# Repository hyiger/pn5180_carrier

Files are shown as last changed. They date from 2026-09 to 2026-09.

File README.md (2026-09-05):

# PN5180 8-Bay NFC Reader Carrier

Carrier board that lets 4 or 8 PN5180 breakout modules plug in over ~30 cm cables with
Molex CLIK-Mate 1.50 mm dual-row (2×5) positive-lock connectors (CLIK-Mate is the white
latching family used on the Prusa LoveBoard) and share one SPI bus with a Seeed Studio
XIAO ESP32C6 soldered flat at the top centre of the board. It runs from the printer's 24 V supply through an MP1584EN buck
module soldered flat onto the carrier. Every part is SMD except the buck module's four
through-hole pads; the XIAO is soldered flat by its castellations. A 74HC138 decodes
3 address lines into the 8 chip selects; a 74HC151 muxes the 8 BUSY lines back to a
single GPIO. The PN5180's IRQ pin is not used — BUSY is the only handshake the SPI
protocol needs.

**GPIO cost: 9 of the XIAO's 11 pins** — SCK, MOSI, MISO, A0, A1, A2, /EN, BUSY, /RST.
D6 and D7 are spare.

Author: hyiger · Rev 1.4 · KiCad 10 files (saved with 10.0.6; KiCad 9 and older cannot open them)

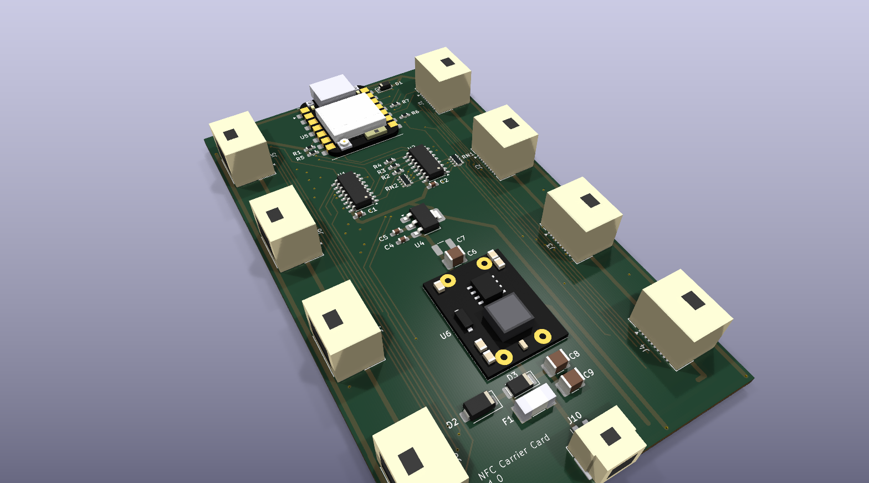
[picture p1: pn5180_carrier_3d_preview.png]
3D preview of the carrier


## Files

| File | Purpose |
|---|---|
| `pn5180_carrier.kicad_pro` | Project file — open this in KiCad 10 |
| `pn5180_carrier.kicad_sch` | Schematic (single A3 sheet, all symbols embedded) |
| `pn5180_carrier.kicad_pcb` | 2-layer PCB, 62.5 × 106.5 mm. Layout in progress: J1–J8 now carry the 2×5 503148-1090 footprints (swapped 2026-09-05) but their tracks still need re-routing; a few other nets unrouted; mounting holes not yet placed. All 35 footprints reference a 3D model |
| `carrier.kicad_sym` + `sym-lib-table` | Project-local symbol library (same symbols, for editing) |
| `carrier.pretty/` + `fp-lib-table` | Project-local footprints: the XIAO castellated SMD pattern (plus the older 2×7-socket version, geometry from Seeed's OPL library), the MP1584EN module pads, the CLIK-Mate 503148-1090 2×5 receptacle (from Molex's catalog drawing — KiCad ships no dual-row CLIK-Mate footprint), and copies of the stock 502494-0270 (J10) and NANO2 (F1) footprints that differ only in pointing at a project 3D model |
| `pn5180_carrier_schematic.pdf` / `.png` | Rendered schematic, no KiCad needed |
| `pn5180_carrier_bom.csv` | Full BOM: refs, qty, MPN, Mouser #, footprint, DNP flag |
| `pn5180_carrier_mouser_order.csv` | One-board order list for Mouser's BOM tool (populated parts and cable-side parts with spare terminals) |
| `gerbers/`, `gerbers.zip` | Preview gerber/drill export of the unfinished layout, still with the 1×10 connectors — not a fab package |
| `check_netlist.py` | Asserts the exported netlist against the intended connectivity (`kicad-cli sch export netlist --format kicadsexpr -o net.txt pn5180_carrier.kicad_sch`, then `python3 check_netlist.py net.txt`) |
| `gen_kicad.py` | Historical generator that produced the schematic, symbol library, footprints and BOM through rev 1.3 (KiCad 7 format). The KiCad files have been hand-edited since and are authoritative — don't re-run it over them |
| `CLAUDE.md`, `MEMORY.md` | Design guide and decision log: verified part data, layout state, ERC/DRC baseline, open items |
| `.gitignore` | Keeps KiCad's transient files (`.history/`, `.kicad_prl`, lock files), kicad-cli check outputs and `renders/` out of git |
| `carrier.3dshapes/` | Simplified VRML 3D models (boxes with the right envelopes and colours) for the parts KiCad ships no model for: the 2×5 and 1×2 CLIK-Mate receptacles, the XIAO (flat, plus a socketed variant), the MP1584EN module (black no-trimmer type), the NANO2 fuse. Generated by `tools/gen_3d_models.py`; drop in vendor STEP files when you have them |
| `tools/` | `gen_clikmate_2x5_fp.py` (the 503148-1090 footprint), `gen_xiao_smd_fp.py` (the XIAO castellated footprint), `gen_3d_models.py` (the models above), `render_3d_preview.py` (top, isometric and close-up PNGs of the board via `kicad-cli pcb render`; run with KiCad's bundled Python) |
| `pn5180_carrier_3d_preview.png` | Rendered 3D view of the board with those models |

Footprints reference the stock KiCad libraries and every name was verified against
the 10.0 library set (`Capacitor_SMD`, `Diode_SMD`, `Package_SO`, `Resistor_SMD`, …). If a newer
library renames one, reassign it in the footprint tool — nothing in the netlist
depends on the footprint. Command-line checks use KiCad's `kicad-cli`: `sch erc`,
`pcb drc --schematic-parity`, and `sch export netlist` followed by `check_netlist.py`.

## Connector pinouts

### J1–J8: bay connectors (Molex 503148-1090, CLIK-Mate 1.50 mm 2×5 dual-row right-angle SMT)

Build cables by Molex circuit number: cavity *n* of the 503149-1000 housing is signal *n*,
and signals 1–9 follow the first nine positions of the common red PN5180 module's header,
so the module end is a straight 1-to-9 run plus the second GND (cavity 10 into the same
module GND as cavity 9). Molex's catalog drawings number the two rows as stacked pairs —
odd circuits (1, 3, 5, 7, 9) in one row, even (2, 4, 6, 8, 10) in the other — which puts
5V over 3V3, /RST over NSS, MOSI over MISO, SCK over BUSY and the two GNDs in the last
column. That pairing and the receptacle's lead order are read off the drawings rather than
dimensioned, so before crimping the first cable confirm on Molex's 503149/503148 sales
drawings which end is circuit 1 (and from which face the drawing looks), which row carries
the odd circuits, and the 502579 terminal's insertion orientation. On the PCB the
receptacle's ten leads come out in one 0.75 mm-pitch line, numbered 1 to 10 from the pin-1
end (chamfer and triangle on the footprint), offset half a pitch toward pin 10 because the
even-row tails jog sideways. Pin 10 is a second GND: run it as a separate wire twisted with
SCK and crimp both returns into the module's GND at the far end, which tightens the SCK
return loop over the 30 cm. Verify the module's header order before building cables.

| Pin | Signal | Notes |
|---|---|---|
| 1 | 5V | From carrier 5V rail (module TVDD / RF power) |
| 2 | 3V3 | From the carrier LDO (U4), direct |
| 3 | /RST | Shared by all bays |
| 4 | NSS | Bay-specific, from 74HC138 output *n* |
| 5 | MOSI | Shared |
| 6 | MISO | Shared (module tri-states when NSS high) |
| 7 | SCK | Shared |
| 8 | BUSY | Bay-specific, to 74HC151 input *n*, 100k pull-down (RN1/RN2) |
| 9 | GND | |
| 10 | GND | Second return — twist with SCK in the harness |

Bay *n* ↔ J(n+1) ↔ 74HC138 Y*n* ↔ 74HC151 D*n*. Bay 0 is address 000, bay 7 is 111.

Most PN5180 modules expect both 5 V and 3.3 V supplied (3.3 V for VBAT/PVDD, 5 V for the
RF stage), so the carrier feeds both. If your modules regulate 3.3 V onboard and drive
that pin as an *output*, leave pin 2 out of the cable rather than paralleling two LDOs.

### U5: Seeed XIAO ESP32C6, soldered flat on castellated pads

Pin numbers follow Seeed's own symbol/footprint: 1–11 = D0–D10, 12 = 3V3 out, 13 = GND,
14 = 5V (USB VBUS). Pins 1 (D0) and 14 (5V) are at the USB end. The footprint
(`carrier:Seeed_XIAO_ESP32C6_SMD`) puts 14 SMD pads of 1.5 × 2.5 mm under the module's
castellations (2.54 mm pitch, rows 17.8 mm apart, extending 1.25 mm past the module edge
for the fillet) and carries the 21 × 17.8 mm outline, the USB-C overhang and an antenna
marker — place the XIAO with the USB end at the carrier's top edge and the antenna end
inboard, and keep copper off both layers under the antenna end. The socketed alternative
(`Seeed_XIAO_2x7_Socket`, two Würth 61300711821 1×7 headers) stays in the library.

| Signal | XIAO pin | Symbol pin | GPIO* | Note |
|---|---|---|---|---|
| SCK | D8 | 9 | 19 | hardware SPI SCK, via R6 33 Ω |
| MISO | D9 | 10 | 20 | hardware SPI MISO |
| MOSI | D10 | 11 | 18 | hardware SPI MOSI, via R7 33 Ω |
| /EN | D3 | 4 | 21 | → 74HC138 /E1 (acts as NSS) |
| A0 | D0 | 1 | 0 | |
| A1 | D1 | 2 | 1 | |
| A2 | D2 | 3 | 2 | |
| BUSY | D4 | 5 | 22 | 74HC151 output (I²C SDA pin, unused as such) |
| /RST | D5 | 6 | 23 | shared reset to all bays |
| spare | D6 | 7 | 16 | NC (UART0 TX) |
| spare | D7 | 8 | 17 | NC (UART0 RX) |
| 3V3 out | — | 12 | | NC — the carrier has its own 3V3 LDO |
| GND | — | 13 | | |
| 5V | — | 14 | | from carrier 5V through D1 |

\* GPIO numbers per Seeed's pin diagram; write firmware with the `D0…D10` names from the
board's `pins_arduino.h` and they can't be wrong. `SPI.begin()` with no arguments uses
D8/D9/D10.

**Power path:** Seeed states the XIAO's 5V pin is the raw USB VBUS and that an external
supply must go through a diode. D1 (PMEG2010AEH, 0.3 V drop at our current) does that, so
USB can stay plugged in for flashing while the carrier is powered — neither source can
push into the other. The XIAO's own LDO makes its 3.3 V from ~4.7 V; that's fine. With the
carrier unpowered, USB alone runs the XIAO and D1 keeps VBUS out of the carrier's 5 V rail.

### J10: 24 V input (Molex 502494-0270, CLIK-Mate 2.00 mm 1×2 right-angle SMT)

| Pin | Signal |
|---|---|
| 1 | +24 V from the printer PSU |
| 2 | GND (printer PSU return) |

**Tapping the Core One.** Take it from the PSU's 24 V output terminals — put a crimped
fork/spade terminal under the existing screw next to the xBuddy's lead, positive and
return together, 22 AWG is plenty. Check polarity with a meter before you plug the
carrier in; the connector is keyed but the PSU end isn't. Load is ≤ ~0.4 A at 24 V worst
case (the module's 1.5 A limit at 5 V), typically well under that, so the PSU's headroom
is not a concern. The xBuddy's MMU port also carries firmware-switched 24 V, but it's only
enabled when an MMU is configured, so the PSU terminals are the practical tap.

**Input stage (all on the carrier):** F1 1 A (NANO2 451/453, fast-acting — see open item 13) → D2 SMAJ28A TVS (clamps motor
regen spikes; a reversed input forward-biases it and blows F1) → D3 PMEG6030EP reverse
Schottky (keeps the reversed input off C8/C9 and the module; F1 still blows through D2,
so replace it after fixing the miswire) → C8/C9 2 × 10 µF 50 V → U6.

**Buck (U6): MP1584EN mini module, mounted flat.** The footprint has four 3 mm
through-hole pads on the module's 18.54 × 8.13 mm pad rectangle; lay the module on the
carrier and solder down through its own plated holes, or stand it on four header-pin
stubs — both work on the same pads. IN pads at the "IN" silk end, OUT at "OUT", "+" marks
the top row. Module pad labels vary between makers, so check the module's own silkscreen
against the footprint before soldering.

Three things about this module on a 24 V rail:

- It's rated 28 V max. The TVS (28 V standoff, clamping from ~31 V) and C8/C9 are what
  keep spikes off it — don't leave them out to save parts.
- It's the **fixed 5 V output** variant (black PCB, no trimmer — the one modelled in
  3D). Don't substitute the adjustable type: a bumped pot can put up to 20 V into the
  readers and the XIAO. Check 5.0 V at OUT+ on the bench before fitting the readers.
- The seller's own guidance is 1.5 A continuous without a heatsink. The carrier's real
  draw is well under 1 A (one RF field at a time), so that's fine; give it some copper
  under the pads anyway.

### Cables (~30 cm)

Bay cable: 503149-1000 dual-row housing at the carrier with 10 × 502579 terminals on
24–28 AWG stranded wire — the terminal takes insulation of 0.78–1.28 mm OD, so use
thin-wall UL1061/UL1571-type wire and check the specific wire's maximum OD against 1.28 mm
(common UL1007 24 AWG at ~1.5 mm is too fat, and some UL1061 24 AWG is specified at
1.3 mm); 24 AWG for 5V/GND is plenty at ≤ 0.25 A per bay — and a 2.54 mm DuPont-style
female on the module end (or solder to the module header). Power: the 24 V cable stays on the 2.00 mm family, 502439-0200 housing
with 502438 terminals on 22 AWG. The XIAO is soldered to the carrier, so bay and power
cables are the only cables.

The housing latches inside the receptacle (the CLIK; one inner lock on the 10-circuit
housing) and releases with a squeeze — no tools. Molex's hand crimpers are expensive
(distributor listings name 200218-7400 for the 1.50 mm 502579 and 63819-2800 for the
2.00 mm 502438 — not checked against Molex's tooling spec); both are small open-barrel
terminals and a small-barrel ratchet crimper (Engineer PA-09 or an IWISS SN-01BM-class
tool) does the job — pull-test the first few crimps, because with 24–28 AWG in a 1.5 mm
terminal the tool is what makes or breaks a cable. Molex also sells pre-crimped CLIK-Mate 1.50 leads
(79758-1011: 300 mm, 24 AWG UL1061, terminal on both ends, packs of 10 at RS) — cut one
end off and solder it to the module header if you'd rather skip crimping.

Eight 30 cm unterminated stubs hanging off one SPI bus is a real transmission-line load,
so the design takes three precautions:

- **R6/R7 (33 Ω) in series with SCK and MOSI**, a few mm from the XIAO's SCK/MOSI pads and
  before the bus fans out — proper source termination for the star, taking the edge off
  the ESP32's ~2 ns rise times. Fit 0 Ω if you scope it and it's clean; 47–68 Ω if you
  see ringing.
- **SPI clock ≤ 1 MHz.** The PN5180 doesn't need more for inventory polling, and a 1 µs
  bit period gives the reflections on a 30 cm stub (a few ns round trip) time to settle.
- **Lowest ESP32 drive strength that works:** `gpio_set_drive_capability((gpio_num_t)D8,
  GPIO_DRIVE_CAP_0)` (and `D10` for MOSI) slows the edges further.

Route GND wires as close to SCK as the harness allows. MISO is driven by the PN5180 (slower
edges) and needs nothing extra. NSS/BUSY see one stub each and are fine.

## How the selection logic works

- `A0..A2` → 74HC138 address inputs **and** both 74HC151 select inputs.
- `/EN` → 74HC138 `/E1` (G2A). Low = the addressed bay's NSS goes low; high = every NSS high.
  Wire the library's "NSS" pin to `/EN` and it just works — the library toggles NSS,
  the decoder routes it.
- `BUSY` (XIAO D4, symbol pin 5) is the 74HC151 output = the BUSY of the addressed bay. Wire
  it to the library's "BUSY" pin.
- `/E2` is grounded, `E3` tied high; 74HC151 `/E` grounded (always enabled).
- R6/R7 sit between the ESP32 and the SCK/MOSI bus (nets `SCK_IN`/`MOSI_IN` on the ESP32 side).
- Pull-ups on `/EN` and `/RST` and pull-downs on `A0..A2` define everything while the
  ESP32 is booting or unplugged. The 4×100k arrays RN1/RN2 keep unfitted bays' BUSY
  inputs from floating. Bay *n* uses element (*n* mod 4)+1 of RN(1 + *n*÷4): pin
  (*n* mod 4)+1 to the signal and its opposite pin (8, 7, 6, 5) to GND — the standard
  1–8/2–7/3–6/4–5 pairing.

**Rule:** change `A0..A2` only while `/EN` is high, or two NSS lines can glitch low
during the decoder transition.

## Firmware sketch (ATrappmann PN5180 library)

```cpp
// Seeed XIAO ESP32C6 soldered to the carrier (Arduino-ESP32 core 3.x, board "XIAO_ESP32C6")
#define PIN_A0   D0
#define PIN_A1   D1
#define PIN_A2   D2
#define PIN_EN   D3     // -> 74HC138 /E1, acts as "NSS" for the addressed bay
#define PIN_BUSY D4     // <- 74HC151 Y
#define PIN_RST  D5
#define BAYS      8     // 4 for a half-populated board
// SCK D8 / MISO D9 / MOSI D10 are the board's hardware SPI pins

PN5180ISO15693 nfc(PIN_EN, PIN_BUSY, PIN_RST);   // one instance for all bays

void selectBay(uint8_t n) {
  digitalWrite(PIN_EN, HIGH);            // deselect everything before changing address
  digitalWrite(PIN_A0, n & 1);
  digitalWrite(PIN_A1, (n >> 1) & 1);
  digitalWrite(PIN_A2, (n >> 2) & 1);
}

void setup() {
  pinMode(PIN_A0, OUTPUT); pinMode(PIN_A1, OUTPUT); pinMode(PIN_A2, OUTPUT);
  pinMode(PIN_EN, OUTPUT); digitalWrite(PIN_EN, HIGH);
  nfc.begin();                           // SPI on D8/D9/D10; keep the SPI clock <= 1 MHz
  gpio_set_drive_capability((gpio_num_t)D8,  GPIO_DRIVE_CAP_0);   // soften SCK/MOSI edges
  gpio_set_drive_capability((gpio_num_t)D10, GPIO_DRIVE_CAP_0);
  // shared /RST: pulse once, then finish the post-reset handshake per bay
  digitalWrite(PIN_RST, LOW);  delay(10);
  digitalWrite(PIN_RST, HIGH); delay(10);
  for (uint8_t b = 0; b < BAYS; b++) {
    selectBay(b);
    while (!(nfc.getIRQStatus() & IDLE_IRQ_STAT)) {}   // add a timeout in real code
    nfc.clearIRQStatus(0xFFFFFFFF);
  }
}

void loop() {
  for (uint8_t b = 0; b < BAYS; b++) {
    selectBay(b);
    nfc.setupRF();                       // RF on, this bay only
    uint8_t uid[8];
    bool present = (nfc.getInventory(uid) == ISO15693_EC_OK);
    nfc.setRF_off();                     // field off before moving to the next bay
    updateBay(b, present, uid);          // debounce: 2-3 misses before "removed"
  }
}
```

The stock library's `while (digitalRead(BUSY))` loops have no timeout; add one
(a few ms) so an empty bay or a wedged module can't hang the sweep.

## Layout notes

The 2-layer PCB in `pn5180_carrier.kicad_pcb` follows these rules; the current routing
state and the ERC/DRC baseline are tracked in `MEMORY.md`.

- Ground plane on one layer; SPI signals short, routed as a star or short daisy chain
  from U5 to the bay connectors. With 8 loads plus cable capacitance, ≤ 1 MHz SPI.
- U5 at the top centre, USB-C end at the top board edge (the rule is a 1–2 mm overhang;
  as placed the module edge sits 0.5 mm inside and only the USB-C shell is 1.05 mm proud),
  antenna end (opposite the USB) pointing inboard with
  a copper keep-out on both layers under it. The XIAO is soldered flat by its
  castellations (no sockets); it also has an external-antenna u.FL if the rack's metal
  gets in the way.
- Bay connectors down both long edges (J5–J8 left, J1–J4 right), in bay order, so cables
  don't cross. The 503148 receptacles are SMT: ten 0.55 mm signal pads at 0.75 mm pitch
  in one line at the rear (reflow, or drag-solder with plenty of flux) and two solder-nail
  pads ("MP" in the footprint) at the front corners — the nails, not the signal pins, take
  the cable-pull load, so give them full paste and don't thin the copper under them.
  Right-angle parts: the cable leaves flat along the board plane. The 2×5 body is 11.8 mm
  long against the old 1×10's 24.0 mm, so the connector columns can tighten up. **J1–J8
  were swapped to the 2×5 footprint on 2026-09-05** (same positions and orientations,
  nail pads outboard); their tracks still have to be re-routed, then refill zones, run
  DRC and regenerate the gerbers (CLAUDE.md open item 12).
- R6/R7 within a few mm of U5 pins 9/11 (D8 SCK / D10 MOSI), before the traces fan out.
- U1/U2 near U5 (short A0–A2, /EN, BUSY traces); the eight NSS/BUSY lines then run out
  to the connector edge.
- U6 module: C8/C9 right at its IN pads, a solid GND pour under it, and keep it away from
  the SPI lines and the XIAO's antenna (it switches at ~1.5 MHz with a small inductor).
- F1/D2/D3 near J10; C6/C7 and C4 near U4; C1/C2 within a few mm of their IC VCC pins.
- U4 (SOT-223) with a copper pour on the tab (tab = OUTPUT, part of the 3V3 net); at ~200 mA on 3V3 it dissipates ~0.35 W.
- M3 mounting holes are still to be added (not in the schematic).
- For a 4-bay build simply leave J5–J8 (and RN2) unpopulated. Firmware `BAYS = 4`.

## BOM (all SMD except U6's four pads)

Rev 1.4. Every symbol in the schematic carries `Manufacturer`, `MPN` and `Mouser` fields,
so KiCad's own BOM export reproduces this table. `pn5180_carrier_mouser_order.csv` can be
uploaded directly to Mouser's BOM tool.

| Ref | Qty | Part | Mouser # | Footprint |
|---|---|---|---|---|
| U1 | 1 | TI SN74HC138DR | 595-SN74HC138DR | Package_SO:SOIC-16_3.9x9.9mm_P1.27mm |
| U2 | 1 | TI SN74HC151DR | 595-SN74HC151DR | Package_SO:SOIC-16_3.9x9.9mm_P1.27mm |
| U4 | 1 | TI TLV1117LV33DCYR, 3.3 V 1 A ceramic-stable LDO | 595-TLV1117LV33DCYR | Package_TO_SOT_SMD:SOT-223-3_TabPin2 |
| J1–J8 | 8 | Molex 503148-1090, CLIK-Mate 1.50 mm dual-row RA SMT receptacle 2×5 (1 A/contact) | 538-503148-1090 | carrier:Molex_CLIK-Mate_503148-1090_2x05-1MP_P1.50mm_Horizontal |
| U5 | 1 | Seeed Studio XIAO ESP32C6 (SKU 113991182) — user-supplied, soldered flat | 713-113991182 (verify) | carrier:Seeed_XIAO_ESP32C6_SMD |
| D1 | 1 | Nexperia PMEG2010AEH, Schottky 20 V 1 A, SOD-123 | 771-PMEG2010AEH | Diode_SMD:D_SOD-123 |
| J10 | 1 | Molex 502494-0270, CLIK-Mate 2.00 mm RA SMT receptacle 1×2 (24 V in) | 538-502494-0270 | carrier:Molex_CLIK-Mate_502494-0270_1x02-1MP_P2.00mm_Horizontal (local copy of the stock footprint, with 3D model) |
| U6 | 1 | MP1584EN mini buck module, 22 × 17 mm, fixed 5 V output (no trimmer) — user-supplied (Amazon) | — | carrier:MP1584EN_Module_22x17 |
| F1 | 1 | Littelfuse 0453001.MR, 1 A, NANO2 (451/453 is the fast-acting series — see open item 13) | 576-0453001.MR | carrier:Fuse_Littelfuse-NANO2-451_453 (local copy of the stock footprint, with 3D model) |
| D2 | 1 | Littelfuse SMAJ28A TVS, 28 V standoff, SMA | 576-SMAJ28A | Diode_SMD:D_SMA |
| D3 | 1 | Nexperia PMEG6030EP Schottky 60 V 3 A (reverse polarity) | 771-PMEG6030EP | Diode_SMD:D_SOD-128 |
| C8, C9 | 2 | Murata GRM32ER71H106KA12L, 10 µF 50 V X7R 1210 | 81-GRM32ER71H106KA12L | Capacitor_SMD:C_1210_3225Metric_Pad1.33x2.70mm_HandSolder |
| R1–R5 | 5 | Yageo RC0603FR-0710KL, 10k 1% 0603 | 603-RC0603FR-0710KL | Resistor_SMD:R_0603_1608Metric_Pad0.98x0.95mm_HandSolder |
| R6, R7 | 2 | Yageo RC0603FR-0733RL, 33 Ω 1% 0603 (SCK/MOSI series) | 603-RC0603FR-0733RL | Resistor_SMD:R_0603_1608Metric_Pad0.98x0.95mm_HandSolder |
| RN1, RN2 | 2 | Yageo YC164-FR-07100KL, 4×100k 1% isolated array | 603-YC164-FR-07100KL | Resistor_SMD:R_Array_Convex_4x0603 |
| C1, C2 | 2 | Murata GRM188R71H104KA93D, 100 nF 50 V X7R 0603 | 81-GRM188R71H104KA93D | Capacitor_SMD:C_0603_1608Metric_Pad1.08x0.95mm_HandSolder |
| C4 | 1 | Murata GRM188R61A106KE69D, 10 µF 10 V X5R 0603 | 81-GRM188R61A106KE69D | Capacitor_SMD:C_0603_1608Metric_Pad1.08x0.95mm_HandSolder |
| C5 | 1 | Murata GRM188R60J226MEA0D, 22 µF 6.3 V X5R 0603 | 81-GRM188R60J226MEA0D | Capacitor_SMD:C_0603_1608Metric_Pad1.08x0.95mm_HandSolder |
| C6 | 1 | Taiyo Yuden MSASJ32MAB5227MPNDT1, 220 µF 6.3 V X5R 1210 | 963-MSASJ32MAB5227MP | Capacitor_SMD:C_1210_3225Metric_Pad1.33x2.70mm_HandSolder |
| C7 | 1 | Same — **DNP**, parallel pads for extra bulk | 963-MSASJ32MAB5227MP | Capacitor_SMD:C_1210_3225Metric_Pad1.33x2.70mm_HandSolder |

Cable side:

| Part | Mouser # | Qty / board | Use |
|---|---|---|---|
| Molex 503149-1000 CLIK-Mate 1.50 dual-row positive-lock plug housing 2×5 | 538-503149-1000 | 8 | Bay cables |
| Molex 502579-0000 CLIK-Mate 1.50 crimp terminal, 24–28 AWG, cut strip of 100 | 538-502579-0000-CT | 100 (80 needed) | Bay cables |
| Molex 502439-0200 CLIK-Mate 2.00 positive-lock housing 1×2 | 538-502439-0200 | 1 | 24 V cable |
| Molex 502438-0100 CLIK-Mate 2.00 crimp terminal, loose, 22–26 AWG | 538-502438-0100 | 2 (+spares) | 24 V cable |

Stock check on Mouser, 2026-09-04/05: 503148-1090 1,696 in stock, minimum 1, $1.98 at 10;
503149-1000 7,865, minimum 1, $0.44 at 10; 502579-0000 cut strip 33,700, minimum 100,
$5.70 per 100. An aggregator snapshot the same day showed the receptacle at DigiKey
(11,852, minimum 1), Newark (63, minimum 1) and Arrow (6,046), and the housing at Newark
(6,475, minimum 10); no obsolescence notice on any of these parts.
The finer 503429-0000 terminal (26–30 AWG) is reel-only (20,000) — don't spec it. The
vertical (top-entry) dual-row receptacle is 503154-1090 (2 A/contact, a two-row land
pattern); the right-angle part used here is rated 1.0 A per contact, 30 mating cycles — a
bay draws ≤ 0.25 A.

Mouser numbers follow Mouser's manufacturer-prefix + MPN scheme (595 = TI, 538 = Molex,
603 = Yageo, 81 = Murata, 710 = Würth, 771 = Nexperia, 713 = Seeed, 576 = Littelfuse). 963-MSASJ32MAB5227MP was read from the product page; the
others follow the scheme. Double-check stock and packaging (cut tape vs. reel) at checkout.

Capacitor notes:

- C6 is a 6.3 V X5R part on the 5 V rail. That's inside its rating, but class-2 ceramics
  lose capacitance under DC bias — expect roughly a quarter of its nominal 220 µF at
  5 V. Together with the MP1584EN module's own output capacitor that's plenty for the
  ~250 mA RF-on step; C7 gives you a second set of pads if the rail shows sag when a
  bay's field switches on.
- U4 is a TLV1117LV33, designed for ceramic output capacitors (TI specifies ≥ 10 µF,
  any ESR, stable at 0 mA load). C5's 22 µF 0603 is worth roughly 10–12 µF after
  DC-bias derating at 3.3 V, which meets that minimum; for more margin use a 22 µF in
  0805 or two 0603s in parallel. Don't substitute a classic AMS1117/TLV1117 here
  without changing C5 to a tantalum — those parts need output ESR to stay stable.
- TLV1117LV limits: Vin ≤ 5.5 V (6 V absolute). Fine on a regulated 5 V rail, but never
  feed J10 from an unregulated "5 V" adapter that idles at 6–7 V. Dropout is ~0.45 V at
  1 A, so 3V3 holds up even if the input droops to 4 V.

## Going to 16 bays

Swap U1 for a 74HC154 (4-to-16), add a second 74HC151 selected by A3 and two more
arrays: 6 select GPIOs, 10 of the XIAO's 11 pins with SPI and /RST. The ESP32-C6 has one
user SPI host, so 16 stubs stay on one bus — keep it at ≤ 1 MHz with the source
termination, or move to an MCU with a second SPI port.

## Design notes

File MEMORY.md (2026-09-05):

# MEMORY — PN5180 8-bay carrier

Context and decision log for whoever picks this up. Written on the evening of 2026-09-03
(local, −07:00; the generator stamps its files 2026-09-04 because that session's clock
ran on UTC) by the design session this log calls "rev 1.5" — the script itself only
stamps rev 1.3, while the sheet title block and README are at 1.4 since 2026-09-05; the
owner has hand-edited since.
Updated 2026-09-04 for the KiCad 10 migration, with measured layout and check status
(history item 11, "Layout state", "Check status"), and 2026-09-05 for the 2×5 CLIK-Mate
switch (item 12), the 3D models (item 13), the flat-mounted XIAO (item 14) and the
fixed-5 V U6 confirmation (item 7). All clock times below are local.

## Owner and purpose

- Owner: **hyiger** (use that name on documents, never a real name or email; git commits
  as `hyiger` with the GitHub no-reply address). Public repo since 2026-09-04:
  https://github.com/hyiger/pn5180_carrier (branch `main`). Experienced FDM
  practitioner and developer; runs a Prusa Core One and a Bambu H2D; maintains Filament DB
  (TypeScript/Electron, NFC spool tags via OpenPrintTag/SLIX2, ACR1552U reader, PN5180
  multi-reader spec) and PrusaSlicer/OrcaSlicer profile tooling. Comfortable with SMD
  hand assembly, KiCad, crimping.
- Purpose: a "spool rack" that detects which NFC-tagged spool is in which of 8 bays.
  One PN5180 breakout per bay, ~30 cm cable to this carrier, ESP32-C6 reports to
  Filament DB over Wi-Fi. Powered from the Core One's 24 V PSU.

## How the design got here (chronological, with reasons)

1. **Architecture**: 8 PN5180 on one SPI bus. RST, SCK, MOSI, MISO shared; NSS and BUSY
   per board. BUSY is mandatory (the PN5180 SPI handshake needs it); IRQ is optional and
   was later dropped entirely. 74HC138 (3 addr + enable → NSS) and 74HC151 (BUSY mux)
   sharing the address lines reduce 8 readers to 5 GPIOs. Rule: change A0–A2 only while
   /EN is high. Firmware sweeps bays round-robin with one RF field on at a time.
2. **Schematic generator**: `gen_kicad.py` writes KiCad 7 format (version 20230121) with
   embedded symbols, global labels on short stubs, deterministic layout. Validated by
   `kicad-cli sch export netlist` plus an assertion script every revision. (KiCad 7 had
   no `sch erc` in the CLI; the owner's KiCad 10 has both `sch erc` and `pcb drc` — item 11.)
3. **Connectors** went KK-254 → Micro-Fit 3.0 SMT (all-SMD request) → C-Grid III box
   header (30 cm cable, "clips in") → **Molex CLIK-Mate 2.00 mm** after the owner showed
   the Prusa LoveBoard's white latching connectors (a Prusa forum thread confirms those are
   CLIK-Mate). Right-angle 502494 chosen because KiCad has verified footprints for
   1×2/1×10/1×12 (the vertical 502443 1×10 is missing from the library). Housings
   502439-xx00, terminals 502438-0100 (22–26 AWG), 3 A/contact.
4. **Passives**: 0603 everywhere possible; 4×100k arrays (Yageo YC164) for BUSY
   pull-downs; 220 µF 6.3 V X5R 1210 (Taiyo Yuden MSASJ32MAB5227MPNDT1, owner's pick)
   instead of an electrolytic, with parallel DNP pads C7. DC-bias derating discussed:
   expect ~¼ of nominal at 5 V.
5. **LDO**: AMS1117 → **TLV1117LV33DCYR** (ceramic-stable, same SOT-223 pinout, Vin
   ≤ 5.5 V/6 V abs). C5 22 µF 0603 is ~10–12 µF effective at 3.3 V, meets TI's ≥ 10 µF.
6. **MCU**: ESP32-DevKitC → ESP32-C6-DevKitC-1 → **Seeed XIAO ESP32C6** (14 pins).
   Socket footprint geometry taken from Seeed's official OPL KiCad library
   (`XIAO-ESP32-C6-DIP`): THT rows 15.24 mm apart, 7 × 2.54 mm, pins 1 (D0) and 14 (5V)
   at the USB end, board 21 × 17.8 mm. Seeed pin numbering: 1–11 = D0–D10, 12 = 3V3 out,
   13 = GND, 14 = 5V. Seeed states the 5V pin is USB VBUS with no diode → D1 Schottky
   added in series from the carrier's 5 V.
7. **Power input**: 5 V terminal → 24 V from the printer PSU. First a discrete
   LMR51420 buck (36 V part, reference design captured), then replaced by an
   **MP1584EN mini module** (owner's preference, fixed-5 V variant, no pot — confirmed
   2026-09-05, and every design file now says fixed 5 V output) on four
   3 mm THT pads at ±9.271 × ±4.064 mm (module drawing: 22.098 × 16.764 mm board,
   18.542 × 8.128 mm pad rectangle). Input protection kept: F1 1 A NANO2, D2 SMAJ28A
   TVS (module is 28 V max), D3 PMEG6030EP reverse Schottky, C8/C9 10 µF 50 V.
8. **IRQ removed** (rev 1.3): U3/C3/RN3/RN4 deleted, bay pin 10 became a second GND,
   XIAO D6 freed.
9. **JP1/JP2**: were solder jumpers (5 V → XIAO, 3V3 → bays). Judged vestigial once D1
   existed and the module type was fixed; **owner removed both in the repo schematic**.
   The generator still has them (rev 1.5) — that is the known divergence.
10. **PN5180 modules need both rails**: 3.3 V feeds VBAT/PVDD, 5 V feeds TVDD (RF).
    With only 3.3 V, SPI works but the field is dead. Carrier supplies both. NXP wants
    TVDD to rise with/after VBAT; the boot-time /RST pulse covers the mild violation.
11. **KiCad 10 migration** (owner, by 2026-09-04): the project was opened and saved in
    KiCad 10.0.6. Consequences: (a) `kicad_sch` is now format 20260306 and `kicad_pcb`
    20260206 — no longer readable by KiCad 9 or older; `gen_kicad.py` still emits the
    KiCad 7 format, so generator output and repo files can only be compared via netlists.
    (b) KiCad 10's local-history feature created `.history/` (its own git repo, ~590
    autosave/save snapshots; Preferences > Common > Project Backup toggles it); opening
    the project also rewrote `pn5180_carrier.kicad_prl`, the ordinary per-user GUI-state
    file every KiCad since 6 writes. (c) `kicad-cli` is at
    `/Applications/KiCad/KiCad.app/Contents/MacOS/kicad-cli` (not on PATH) and now provides
    ERC and DRC. (d) The 10.0 netlist export is pretty-printed one attribute per line
    (7 and 8 wrote one compact node per line); that silently broke `check_netlist.py`'s
    regex parser (0 nets) — made whitespace-tolerant
    2026-09-04, and its `24V_F` expectation renamed to KiCad's auto-name `Net-(D2-K)`
    because that node carries no label in the schematic (nor in the generator). (e) ERC
    reports 81 `lib_symbol_mismatch` warnings: every embedded `power:` symbol differs from
    KiCad 10's power library. Cosmetic. (f) Gerbers and drill files were exported to
    `gerbers/` at 21:46 and zipped at 21:48. They match the current PCB (the 22:06 save is
    byte-identical to the 21:46:42 local-history snapshot; the 21:42:36 one differs only
    in two plot-setting lines the export wrote) but five nets were still unrouted, there
    are no mounting holes, and they carry the skewed right edge (g) — a preview, not a
    fab package. (g) The owner moved the outline out at 18:28–18:29: left edge 109.5 →
    108.0, right edge 169 → 170.5 — 1.5 mm per side, three times the 0.5 mm discussed —
    but the bottom-right corner only reached 170.0, so the right edge ran (170.5, 52) →
    (170.0, 158.5); DRC does not flag such a thing. **Fixed at 23:25** on the owner's
    instruction by editing the two Edge.Cuts coordinates in the file (KiCad closed, backup
    taken): outline is a true 108–170.5 × 52–158.5 rectangle again; DRC unchanged (15
    violations, 10 unconnected, 0 parity). The stored zone fills still stop at the old
    slanted edge until the zones are refilled in the GUI, and `gerbers/` predates the fix.

12. **Bay connectors → CLIK-Mate 1.50 dual row, 2×5** (owner's decision, 2026-09-05). The
    owner asked for a "quick click" Molex 2×5 instead of the 1×10; CLIK-Mate dual row
    exists only at 1.50 mm pitch, so J1–J8 became **503148-1090** (RA SMT, 1.0 A/contact,
    30 cycles, inner positive lock), housing **503149-1000**, terminals **502579-0000**
    (24–28 AWG, insulation OD ≤ 1.28 mm — thin-wall UL1061/UL1571 wire only; the 22 AWG
    option is gone). Mouser checks 2026-09-04/05 (in-app browser; WebFetch is blocked):
    503148-1090 1,696 in stock, min 1, $1.98@10; 503154-1090 (vertical, 2 A) 744, min 1,
    $1.63@10; 503149-1000 7,865, min 1, $0.44@10; 502579-0000 cut strip
    (538-502579-0000-CT) 33,700, min 100, $5.70/100; 503429-0000 (26–30 AWG) reel-only
    20,000 → rejected. OEMsTrade aggregate also showed DigiKey 11,852 / Arrow 6,046 /
    Newark 63 for 503148-1090 and Newark 6,475 for the housing. Alternatives checked and
    set aside: Micro-Fit 3.0 43045-1010 (2×5 RA SMT, 3.0 mm, Mouser 2,318 min 1 — bulky,
    20–24 AWG) and Nano-Fit 105314-1210 (2×5 RA THT, 2.5 mm, Mouser 2,803 min 1 —
    through-hole; housing is 105308-1210, terminals 105300-1200). J10 stays on the 2.00 mm
    family (502494-0270 / 502439-0200 / 502438). KiCad ships no dual-row CLIK-Mate
    footprint: `carrier.pretty/Molex_CLIK-Mate_503148-1090_2x05-1MP_P1.50mm_Horizontal`
    was generated from Molex's catalog drawing (Kyohritsu-hosted Molex Japan catalog,
    p.45): 10 pads 0.55 × 2.70 at 0.75 mm in ONE line at the rear (the two contact rows
    interleave into one lead row), nail pads 1.20 × 4.65 at X ±5.30 toward the front,
    body 11.8 × 8.75, height 9.15. A 600-dpi re-measurement of that drawing (verification
    pass, 2026-09-05) showed the pad line is NOT centred: the odd-circuit tails exit
    straight under the 1.5 mm contact columns (0, ±1.5, ±3.0) and the even-circuit tails
    jog 0.75 mm toward circuit N, so pad k sits at X = 3.0 − 0.75(k−1) (pad 1 +3.0,
    pad 10 −3.75) — a 0.375 mm shift that would otherwise have put every tail on a pad
    gap; and the nail pads reach the mating-face datum (rear edge 4.10 mm behind the pad
    rear edge, centre Y +2.05). Both applied; courtyard front extended to +5.0 because the
    housing may protrude ~0.4 mm past the nails. Still to confirm on Molex SD-503148-1090
    (molex.com is unreachable from the tool network; fine in a normal browser): the
    nail-to-pad-1 dimension and the sequential 1…10 order along the pad line (the drawing
    labels only "circuit 1" right / "circuit N" left, mating face toward the viewer's
    bottom). KiCad's DRC does not apply the netclass clearance between pads of one
    footprint — tested on a scratch board with the project rules, 0 violations at the
    0.20 mm pad gap. Schematic fields, BOM CSV, Mouser CSV, README updated;
    title-block rev bumped to 1.4; netlist (38/189/0) and ERC (82) unchanged. The owner
    ran Update PCB from Schematic at 11:25 on 2026-09-05 (commit a606ea7): J1–J8 are now
    the 2×5 footprints at the old positions and orientations; re-routing is still open.
13. **3D models** (2026-09-05, owner's request): KiCad 10 ships no 3D model for any
    CLIK-Mate connector or the NANO2 fuse, and the two custom footprints had none, so the
    3D viewer showed bare pads. `carrier.3dshapes/` now holds simplified VRML placeholders
    (correct envelopes and colours, built from boxes/prisms) generated by
    `tools/gen_3d_models.py`: 503148-1090 2×5 RA (11.8 × 8.75 × 9.15), 502494-0270 1×2 RA
    (8.0 × 6.95 body with the narrowed nose per the stock F.Fab, height ~6.5 estimated),
    XIAO ESP32C6 (flat; a socketed variant is kept) modelled from the owner's photos:
    rounded 21 × 17.8 board, 14 half-hole castellations, USB-C 8.94 wide overhanging the
    +X end to 12.05, R button on the pin-1 (−Y) side and B opposite with LEDs behind them,
    13 × 11.3 white shield starting 6.5 mm behind the USB edge, u.FL at the antenna-end
    pin-1 corner, chip antenna along the antenna end on the +Y half; MP1584EN module per
    the owner's photo (black 22.1 × 16.8 PCB, 6.3 mm shielded inductor, SOIC-8 with pins
    along X, 0805 ceramics, SOD-123, four plated corner holes, **no trimmer**); Littelfuse
    NANO2 451/453 (6.1 × 2.69 × 2.69). Referenced from carrier.pretty; J10 and F1 got
    project-local copies of the stock footprints that differ only in the model path and a
    descr note, and their Footprint fields now say `carrier:`. The PCB's embedded
    footprints were text-patched to reference the models (all 35 resolve). Preview:
    `pn5180_carrier_3d_preview.png`, `tools/render_3d_preview.py`. Vendor STEP files
    (Molex 503148-1090 / 502494-0270 from molex.com or Mouser's "STP File", Seeed's XIAO
    ESP32C6 STEP from its wiki) would replace the placeholders; not fetched — molex.com is
    unreachable from the tool network and a download needs the owner's OK.
14. **XIAO soldered flat, no sockets** (owner, 2026-09-05). New footprint
    `carrier:Seeed_XIAO_ESP32C6_SMD` (`tools/gen_xiao_smd_fp.py`): 14 SMD pads 1.5 × 2.5 at
    2.54 mm on the module edges (Y ±8.9, rows 17.8 mm apart), pin 1 at (+7.62, −8.9), the
    same 1–14 numbering as the socket footprint, so the netlist is unchanged; USB-C overhang
    and antenna marker on F.Fab; courtyard includes the overhang. U5's Footprint field and
    the BOM CSV changed, the Würth 61300711821 sockets left the Mouser order list, and U5
    was swapped on the PCB by script (pcbnew, same position/rotation/nets/fields; its F.Cu
    tracks end at the old hole centres and overlap the new pads by only ~0.1 mm — extend
    them 1.28 mm; /EN (pad 4) is OPEN because its route jogged to B.Cu into the old THT
    pad; 3 shorts under pad 5 (BUSY); the swap left the MPN/Mouser fields visible on silk;
    the XIAO's underside pads need an F.Cu keep-out — see CLAUDE.md open item 14). Later
    on 2026-09-05 (KiCad closed) the schematic's U5 Description and F1 Value/Description
    got the BOM-CSV wording, and U5's MPN became "XIAO ESP32C6" in schematic, PCB and both
    CSVs (the owner had shortened the PCB field, which stays visible on F.SilkS as the
    module label; the SKU lives in the Description). The socketed footprint and
    its model stay in the library. Fixes from the 3D verification pass applied at the same
    time: half-hole castellations, buttons clear of the corner pads, J10 model on the
    stock F.Fab outline, no trimmer on the U6 model.

## Verified facts (don't re-derive)

Rows without a date come from the 2026-09-03 design session.

| Item | Value | Verified how |
|---|---|---|
| CLIK-Mate 2.00 RA 1×10 (retired 2026-09-05; off the PCB since a606ea7, still in the stale `gerbers/`) | Molex 502494-1070; stock KiCad footprint body 24.0 mm long | KiCad footprint exists; Molex listing |
| CLIK-Mate dual row | only in 1.50 mm; RA SMT 503148-xx90 (10–24 ckt, 1.0 A), vertical SMT 503154-xx90 (8–34 ckt, 2.0 A), housing 503149-xx00, terminals 502579-0000 (24–28 AWG) / 503429-0000 (26–30 AWG); 30 cycles; no stock KiCad footprint. (Earlier note here had "-xx70" and "terminal 502578" — wrong.) | Molex brochure 987650-3302, Molex Japan catalog drawings, Mouser pages 2026-09-05 |
| 503148-1090 land pattern | 10 × 0.55 × 2.70 pads at 0.75 mm in one line at the rear; nails 1.20 × 4.65 at X ±5.30 toward the front (fore-aft position scaled); body 11.8 × 8.75, h 9.15; circuit 1 at the right in the top view with the mating face down | Molex Japan catalog p.45 (Kyohritsu mirror), 2026-09-05 — confirm on SD-503148-1090 |
| XIAO ESP32C6 mechanicals | 2×7 THT at 15.24 mm rows for sockets, castellations on the long edges at 2.54 mm (rows 17.8 mm apart, used flat since 2026-09-05), USB end = pins 1/14, 21 × 17.8 mm | Seeed OPL KiCad lib; owner's photos |
| XIAO 5V pin | direct USB VBUS, needs series diode for external feed | Seeed wiki |
| XIAO SPI | D8 SCK / D9 MISO / D10 MOSI; `SPI.begin()` default | Seeed wiki |
| TLV1117LV33DCYR | 1 A, Vin 2–5.5 V (6 V abs), ceramic-stable, ≥10 µF out | TI datasheet |
| MP1584EN module | 22.1 × 16.8 mm, pads 18.54 × 8.13 mm, 4.5–28 V in, 1.5 A cont. | module dimension drawing |
| LMR51420 (retired) | pinout 1 GND 2 SW 3 VIN 4 FB 5 EN 6 CB; 5 V ref: 10 µH, 2×22 µF, 100k/13.7k, 0.1 µF boot | TI datasheet |
| Taiyo Yuden 220 µF 1210 | MSASJ32MAB5227MPNDT1, 6.3 V X5R, Mouser 963-MSASJ32MAB5227MP, $1.72 | Mouser page |
| Mouser prefixes | 595 TI, 538 Molex, 603 Yageo, 81 Murata, 710 Würth, 771 Nexperia, 713 Seeed, 576 Littelfuse, 994 Coilcraft | live listings |
| Mouser numbers verified on a product page | 963-MSASJ32MAB5227MP, 538-90130-3310 (retired part) | — |
| Mouser numbers pattern-derived (spot-check at checkout) | all Murata 81-…, 713-113991182 (XIAO SKU); 710-61300711821 retired with the sockets | — |
| Würth 1×7 socket (dropped 2026-09-05 — XIAO soldered flat) | 61300711821 (WR-PHD series confirmed) | search |
| JLCPCB 2-layer limits | 0.127 trace/space, 0.3 drill, via 0.45–0.5 pad, 0.5 hole-hole, 0.2 edge, silk 0.15/1.0 | JLC capability pages |
| KiCad on the owner's Mac | 10.0.6; `kicad-cli` at `/Applications/KiCad/KiCad.app/Contents/MacOS/kicad-cli`; stock libs under `…/Contents/SharedSupport/{symbols,footprints,3dmodels}`; bundled Python with `pcbnew` under `…/Contents/Frameworks/Python.framework/Versions/Current/bin/python3` | run 2026-09-04 |
| Stock footprints used by the PCB after the 2026-09-05 swaps, all present in the 10.0 library | nine names: Capacitor_SMD C_0603/C_1210 HandSolder, Resistor_SMD R_0603 HandSolder + R_Array_Convex_4x0603, Diode_SMD D_SMA/D_SOD-123/D_SOD-128, SOIC-16_3.9x9.9mm_P1.27mm, SOT-223-3_TabPin2; F1, J10, J1–J8, U5, U6 use `carrier:` footprints | file check 2026-09-05 |
| Board outline | Rectangle, edge-line centres X 108.0–170.5, Y 52.0–158.5 → 62.5 × 106.5 mm, 0.05 mm stroke (bottom-right corner was at x 170.0 from 18:28 until fixed 23:25) | pcbnew 2026-09-04 23:25 |
| Connector tab pad to board edge (1×10 footprints, pre-swap; with the 2×5 footprints the nail pads reach x 109.575–109.625 / 168.825–168.875, i.e. 1.575–1.675 mm from the edge (min 1.575 on J6/J8) — pcbnew 2026-09-05; the ≥ 1.35 mm 3V3 lane still fits) | J5–J8: tab pads reach x 110.10–110.15, 2.10–2.15 mm to the edge. J1–J4: tab pads reach x 168.30–168.35, 2.15–2.20 mm. End connectors' tab pads are 1.25 mm from the top/bottom edges; J10's tab pads 0.65 mm from the bottom edge | pcbnew 2026-09-04 23:25 |
| Power netclass patterns | `+5V`, `+3V3`, `+24V`, `5V_*`, `24V_*`, `*D2-K*` (Default 0.25/0.25 via 0.6/0.3; Power 0.8/0.25 via 0.8/0.4) | .kicad_pro 2026-09-04 |
| Rasteriser | `cairosvg` absent everywhere; `qlmanage -t -s 2400 -o existing_dir file` → `file.png` works for PDF, footprint SVGs and the portrait board SVG (square render — crops the A3 schematic SVG, use the PDF); Pillow 12 in Homebrew python3 3.14 only | run 2026-09-04 |

## Pinouts and maps (as designed)

Bay connector J1–J8: 1 5V · 2 3V3 · 3 /RST · 4 NSS · 5 MOSI · 6 MISO · 7 SCK · 8 BUSY ·
9 GND · 10 GND. Bay *n* = J(n+1) = 74HC138 Y*n* = 74HC151 D*n* = RN(1+n÷4) element (n mod 4)+1.
Right-hand connectors are rotated 180° relative to the left column (absolute +90° vs −90°),
so pin 1 was at the bottom on J1–J4 and at the top on J5–J8 with the 1×10 parts. After the
2×5 swap (2026-09-05) it is the reverse: pin 1 at the top on J1–J4 and at the bottom on
J5–J8, signal-pad row inboard, nail pads outboard (pcbnew).

XIAO: D0 A0, D1 A1, D2 A2, D3 /EN, D4 BUSY, D5 /RST, D6 spare, D7 spare, D8 SCK, D9 MISO,
D10 MOSI. GPIO numbers per Seeed: D0=0 D1=1 D2=2 D3=21 D4=22 D5=23 D6=16 D7=17 D8=19
D9=20 D10=18 (write code with the D names).

74HC138: 1 A0, 2 A1, 3 A2, 4 /E1=/EN, 5 /E2=GND, 6 E3=3V3, 7/9–15 Y7..Y0, 8 GND, 16 VCC.
74HC151: 4/3/2/1/15/14/13/12 = D0..D7, 11/10/9 = S0..S2, 7 /E=GND, 5 Y=BUSY, 6 /Y NC.

## Layout state (measured with pcbnew on 2026-09-04; earlier numbers came from screenshots)

- Portrait board **62.5 × 106.5 mm** (edge-line centres X 108.0–170.5, Y 52.0–158.5; the
  right edge was skewed to x 170.0 at the bottom from 18:28 until fixed at 23:25 —
  history item 11g).
  J5–J8 down the left edge (centre x 114.0 for J5/J7, 113.95 for J6/J8; rotated −90°),
  J1–J4 down the right (x 164.5, J3 at 164.45; +90°), at y = 65.5 / 92 / 118.5 / 145 —
  the 0.05 mm column misalignments look like hand nudges. Tab (MP) pads outboard, signal
  pads inboard. XIAO U5 at (140, 63) rot 90 at the top centre, USB toward the top edge,
  antenna inboard (F.Cu + B.Cu rule areas x 134.5–145.5, y 67–75.5: no fill/track/via/pad,
  honoured); U1 and U2 side by side below the XIAO; U4/C4/C5 below them; C6/C7; the
  MP1584 module centred; D2/D3/F1/C8/C9 below it; J10 at (139.88, 154) bottom centre, its
  tab pads 0.65 mm from the bottom edge. Top GND pour (priority 1), bottom GND plane,
  479 track segments (112 of them on B.Cu, across 26 nets), 142 vias, 4 zones on
  2026-09-04; after the owner's 2026-09-05 footprint swap and the U5 swap: 452 segments
  (104 on B.Cu), 122 vias, 4 zones (saved unfilled — refill in the GUI).
- **Tab pad to board edge: J5–J8 2.10–2.15 mm; J1–J4 2.15–2.20 mm** (while the right
  edge was skewed, J1–J4 measured 1.66–2.14 mm). Before the owner's 18:28–18:29
  outline move (edges at 109.5/169 in the 18:00 snapshot) the gap was 0.60–0.70 mm, so the
  earlier screenshot estimate (~0.7 mm) was right. The 3V3 outer lane needs ≥ 1.35 mm
  (0.3 edge + 0.8 track + 0.25 Power clearance; the 1.2 mm quoted earlier was
  under-derived), so it now fits everywhere and no further move is needed. Tab-column
  gaps between connectors are ~2 mm — enough for the feeder vias.
- The XIAO module edge is 0.50 mm inside the top edge and the USB-C shell 1.05 mm proud of
  it (the SMD footprint's courtyard, which includes the overhang, crosses the edge by
  1.3 mm) — less than the 1–2 mm overhang the layout rule asks for.
- Power plan delivered as `power_routing_full.png` (not in the repo): 24 V in the bottom
  strip; 5 V trunk from OUT+ down the module centreline, right of C8/C9, via; 3V3 trunk
  from U4's tab down at ~1.3 mm off the module's right pads, via; both feeders on the
  bottom layer along the bottom edge and up under the tab columns to vias in the J7/J8
  and J3/J4 gaps; lanes up the columns; 5 V stubs to pin 1 direct, 3V3 stubs to pin 2
  with one short bottom jog each over the 5 V lane; 3V3 to U1/U2 VCC under the SOIC
  bodies; 5 V right lane continues to the top to feed D1. The "only two bottom-layer
  traces" rule is the plan; the saved board routes every signal group partly on B.Cu.
- Top GND pour: 24 islands. Five hold exactly one GND pad and no via (R2.2, R3.2, R4.2,
  U1.5, J1.9 — U1.5 is /E2 of the 74HC138, so if it floats no chip select ever asserts);
  the largest island (~2000 mm², left/centre) has no GND via at all and reaches the plane
  only through THT pads U5.13, U6.2, U6.4; J1.10's island (37 mm²) hangs off a single
  thermal spoke of U5.13. 43 GND vias in total.
- Still missing: mounting holes (no NPTH footprint on the board); stitching vias in the
  top pour pockets; R1/R5 sit top-left with no clean 3V3 path (move beside U1 pins 4–5,
  or accept a jog under A0–A2).
- `gerbers/` (21:46) and `gerbers.zip` (21:48, 2026-09-04) are stale: made before routing,
  holes and the 23:25 outline fix — regenerate before ordering. The owner refilled the GND
  zones in the GUI at 23:32 (PCB save, committed as a473531).
- **2026-09-05 11:25: the owner swapped J1–J8 on the PCB to the 2×5 CLIK-Mate 503148-1090**
  (Update PCB from Schematic; same positions and orientations). Tracks to them dangle
  until re-routed; the connector columns, power lanes and tab-pad clearances above still
  describe the 1×10 layout. All 35 footprints now reference a 3D model (item 13).
- **2026-09-05 12:15: owner's routing session saved** (commit e281c6a; 368 segments,
  80 vias, zones unfilled). Refilled-DRC shorts 44 → 10, courtyard overlaps 5 → 2 (R1/R5
  only); see "Check status after the owner's 12:15 save" below.

## Check status after the owner's 12:15 save (kicad-cli 10.0.6, 2026-09-05)

- Board as saved (zones unfilled): 200 violations, 159 unconnected, 0 parity. Refilled on
  a scratch copy: **170 violations, 89 unconnected, 0 parity**. Shorts 10: 7 in the J3
  column (NSS2 track on GND pad 9; SCK via + track on pad 1 [+5V]; MISO via on pad 3
  [~{RST}]; MOSI via + track on pad 6 [MISO]; a GND via in the nail pad) and 3 at U5 pad 5
  (BUSY) under the ~{EN} and ~{RST} tracks. 70 clearance, 6 hole clearance (the J3 vias
  above), 13 mask bridges, 54 dangling tracks + 2 dangling vias, 3 starved thermals
  (RN1.5, J2.10, U1.5), 2 courtyard overlaps (U5 with R1 and R5), silk 2 edge + 1
  overlap, 7 text-size warnings. Opens by net: +3V3 11, +5V 10, ~{RST} 10, MISO 10,
  MOSI 9, SCK 9, GND 8, one per NSS0–7/BUSY0–7 (NSS6/NSS7 two), ~{EN} 1 (F.Cu track to
  a B.Cu stub near (130, 65.4), no via), MOSI_IN/SCK_IN/5V_XIAO 1 each (R7/R6/D1 pad 1).
  ERC 82 and the netlist (38/189/0) unchanged after the U6/U5/F1 field edits.

## Check status after the 2×5 and flat-XIAO swaps (kicad-cli 10.0.6, 2026-09-05)

- The board as saved (owner's a606ea7 + the U5 script swap) has its GND zones **unfilled**
  (Update PCB from Schematic drops fills), so DRC on the file as saved over-reports:
  336 violations, 149 unconnected, 0 parity. With zones refilled on a scratch copy (do not
  `--refill-zones` the repo file): **304 violations, 78 unconnected, 0 parity** — all of
  it the pending re-route: 44 shorts (41 at J1–J8: old NSS stubs/vias on the new GND pad 9,
  a GND via in J3's nail pad; 3 at U5 pad 5 under the /EN and /RST tracks), 97 clearance, 27 hole clearance (SCK vias under pad 1 of
  J2/J3/J4), 75 mask bridges, 27 dangling tracks, 1 dangling via, 4 starved thermals
  (RN1.5, U1.5, J7.9, J7.10), 5 courtyard overlaps (U5's castellation pads now reach
  1.25 mm past the module edge, into R1/R5 on one side and R6/R7/D1 on the other — move
  those five ~1.5 mm outward), silk 8 overlap + 7 over copper + 2 edge, 7 text-size
  warnings. Unconnected by net: GND 10, +3V3 10, ~{RST} 9, SCK 9, +5V 8, MOSI 8, MISO 7,
  ~{EN} 1 (U5 pad 4 is open: its route jogged to B.Cu into the old through-hole), one
  each on NSS0–7 and BUSY0–7 (U5's F.Cu tracks end at the old hole centres, overlapping
  the new pads by only ~0.1 mm). ERC 82 and the netlist (38 nets, 189 nodes, 0 problems)
  are unchanged. The 2026-09-04 baseline below applies only to the pre-swap board.

## Check status (kicad-cli 10.0.6, 2026-09-04, files as saved 22:06 — pre-swap baseline)

- `check_netlist.py`: 38 nets, 189 nodes, 0 problems.
- ERC: **1 error** — `pin_to_pin`: PWR_FLAG #FLG01 is attached to U6 pin 3 (OUT+), which
  is already a Power-output pin; delete that flag. **81 warnings** — all
  `lib_symbol_mismatch` on `power:` symbols (+3V3, +5V, +24V, GND, PWR_FLAG — exactly the
  81 power-symbol instances): the copies embedded by gen_kicad.py differ from KiCad 10's
  power library. Cosmetic; "Update Symbols from Library" clears them.
- DRC with `--schematic-parity`: 0 parity issues. **3 errors** — `starved_thermal` on
  RN1 pin 5, U1 pin 5 and J1 pin 9 (one spoke into the top GND pour instead of two).
  **12 warnings** — U5's USB-C shell silk outline crossing the top edge ×2, D3 reference
  overlapping its outline, and 9 text height/thickness violations on 6 texts (U5 "ANTENNA"
  and U6 "OUT"/"IN" fail both height and thickness, the two U6 "+" fail height, the board
  text "NFC Carrier Card v1.0" fails thickness at 0.10 mm). **10 unconnected items** — the 5 orphaned
  GND pads listed under Layout state (each on its own pour island, no via) plus one open
  each on +3V3, ~{RST}, MOSI, MISO, SCK. DRC names different track segments for those
  opens on each run; compare by net, not by description.

## Things learned the hard way

- A wire ending on the middle of another wire needs a junction symbol at that point.
  The KiCad 7 session also split the through-wire; a test schematic under 10.0.6 shows
  the junction alone connects and the split changes nothing. If in doubt, run the
  netlist check.
- `kicad-cli` (7.0 and 10.0.6 alike) prints only "Failed to load schematic" on any parse
  error; bisect by section. Unescaped quotes inside strings were the first culprit.
- Power-symbol value text rotates with the symbol; side-mounted rotated power symbols
  need a separate upright text object.
- Mouser truncates long MPNs in its own part numbers (the Taiyo Yuden cap); don't
  assume prefix + full MPN for 18+ character MPNs.
- The vertical CLIK-Mate 2.00 1×10 (502443-1070) has no KiCad footprint even though
  1×9 and 1×12 do; the footprint is fully formulaic (L = n + 2 mm half-length) if one
  is ever needed.
- The 74HC138/151 approach scales to 16 bays with a 74HC154 and a second 74HC151 on A3.
- KiCad 10 pretty-prints the netlist and board files one attribute per line (7 and 8
  wrote compact one-node-per-line netlists). Regexes written against the compact form
  match nothing and report "0 nets" without error; `(gr_line …)` likewise spans several
  lines. Use `\s+` between tokens, or better, the bundled `pcbnew` Python for geometry.
  Also: `grep -c "(via"` over-counts by the two `(vias not_allowed)` rule-area lines.
- `kicad-cli` on macOS is not on PATH; the bundle path is in the Verified facts table.
  `pcbnew.LoadBoard` prints a wxApp "traits" assert to stderr that can be ignored, and
  `Board.Zones()` returns a tuple in 10 (no `.size()`).
- `cairosvg` is not installed here; `qlmanage -t` renders SVG or PDF to PNG well enough
  to inspect.
- `kicad-cli pcb export svg` in 10.0.6 defaults to the deprecated `--mode-single` (one
  file at `-o`) and warns about it; a directory at `-o` fails with "Failed to create
  file", exit 2. Pass `--mode-single` or `--mode-multi` explicitly. `fp export svg -o`
  creates the directory only when the path ends in `/`; otherwise, if the directory is
  missing, it prints "Error creating svg file" but still exits 0.
- `qlmanage -t` renders into a square, so it crops landscape SVGs (the A3 schematic loses
  J5–J8 and the title block); rasterise the PDF export instead. Its `-o` directory must
  exist, or it claims success and writes nothing.
- The ERC JSON reports positions in mm ÷ 100 although `coordinate_units` says "mm"
  (#FLG01 at 1.2192, 0.6858 = 121.92, 68.58 mm on the sheet). The netlist export omits
  #PWR/#FLG symbols entirely — a PWR_FLAG's net has to be found by wire tracing.
- DRC on a `.kicad_pcb` copied outside the project directory loses the project rules and
  the `carrier` library (default 0.5 mm edge clearance, `lib_footprint_issues`) and reports
  a different set of findings; and the track segments DRC names for an unconnected net
  differ between runs on the same file.
- KiCad 10's user-level `~/Library/Preferences/kicad/10.0/fp-lib-table` is a nested
  `(type "Table")` entry pointing at the bundle's template table under
  `Contents/SharedSupport/template/`; scripts that read the user table directly see no
  per-library rows.
- `git status`/`diff`/`add`/`gc` inside `.history/` rewrite its `.git/index`; only
  `git log`, `rev-list`, `show` are read-only there.
- KiCad VRML models: 1 unit = 0.1 inch (divide mm by 2.54); model +Y is footprint −Y (up
  on screen); after that Y mirror, reverse each face's winding or `kicad-cli pcb render`
  perspective views show the faces black while the top view still looks fine. Material
  diffuseColor is honoured. `${KIPRJMOD}` in model paths resolves only when a `.kicad_pro`
  sits beside the board, so preview scripts must copy the project file too. KiCad's DRC
  ignores missing 3D models; `pcb export step` lists them as "File not found".
- Distributor access from the tool network (2026-09-05): mouser.com and digikey.com block
  WebFetch; Mouser product pages load in the in-app browser (stock, "Minimum:", price
  breaks readable with get_page_text) for roughly a dozen loads, then "Access denied";
  DigiKey and ManualsLib sit behind Cloudflare checks; molex.com times out for WebFetch
  and serves its PDFs as downloads in the browser. Working sources: docs.rs-online.com
  PDFs, *.rsdelivers.com, oemstrade.com (Octopart-style aggregator), and the Kyohritsu
  mirror of Molex Japan's catalog (drawings for the 1.50 mm CLIK-Mate family).

## Open questions for the owner

- ~~Move the board outline out 0.5 mm per side?~~ Done by the owner on 2026-09-04
  18:28–18:29, by 1.5 mm per side; tab-pad-to-edge is now 2.10–2.15 mm left, 2.15–2.20 mm
  right (pcbnew, after the 23:25 corner fix) and the 3V3 lane fits. (1×10 figures; the
  2×5 nail pads sit 1.575–1.675 mm from the edge — still fits.)
- ~~Straighten the right edge?~~ Owner chose x = 170.5; done 23:25. Refill zones and
  re-export gerbers in the GUI.
- Delete PWR_FLAG #FLG01 on U6 OUT+ (the one ERC error)? Update the embedded `power:`
  symbols from the KiCad 10 library to clear the 81 ERC warnings?
- Add a `24V_F` global label to the F1–D2–D3 node and drop the `*D2-K*` netclass pattern?
  Today the node is unlabeled; `check_netlist.py` expects the auto-name `Net-(D2-K)` and
  the Power netclass reaches it only via `*D2-K*` — editing D2 renames the net and
  silently drops it to the Default class.
- Is routing signals on B.Cu (104 segments today) accepted, or does the "two feeders
  only" bottom-layer rule still stand?
- U5 sits 0.45 mm inside the top edge instead of overhanging 1–2 mm: move it up, or
  relax the rule?
- ~~README, BOM CSV and schematic notes lag the design (JP1/JP2, KiCad 7)?~~ Updated
  2026-09-04: README rewritten for KiCad 10 and the PCB, JP1/JP2 removed everywhere,
  renders re-exported; title-block comment 1 now reads "BUSY mux". Note: those three
  schematic text edits were made on disk while KiCad was open, so the schematic editor
  must be reverted (File > Revert) before its next save.
- Delete the stray repo file `rites next to this script#`?
- Where do the M3 holes go? (Suggested: inboard of each connector column at the
  J5/J6 and J7/J8 gap levels, clear of tab pads.)
- Harness spec is now 24–28 AWG thin-wall (502579 cavity, OD ≤ 1.28 mm), second GND
  twisted with SCK — still 30 cm? Buy Molex pre-crimped 79758-1011 leads (24 AWG, 300 mm,
  packs of 10) instead of crimping?
- 2×5 pin pairing: keep the module-header order (5V/3V3, /RST/NSS, MOSI/MISO, SCK/BUSY,
  GND/GND stacked) or re-pair so SCK sits over a GND? (Changes the netlist and README.)
- ~~Move J10 to the 1.50 family too?~~ Decided 2026-09-05: **J10 stays CLIK-Mate 2.00 mm**
  (502494-0270 / 502439-0200 / 502438, 3 A contacts, 22 AWG to the PSU); the 1.50 mm
  terminals top out at 24 AWG thin-wall and 2 A. Two terminal types is the accepted cost.
- Vertical 503154-1090 (2 A, top entry) instead of the right-angle 503148-1090?
- F1: the BOM's Littelfuse 0453001.MR is in the NANO2 451/453 very-fast-acting family,
  not Slo-Blo (that is 452/454, e.g. 0454001.MR) — keep fast and fix the description, or
  switch part and footprint? (Raised by the 2026-09-05 verification pass; check the
  Littelfuse datasheet.)
- Retire `gen_kicad.py`, or port the JP1/JP2 removal and any other hand edits into it?
- 4-bay build variant: J5–J8 and RN2 unpopulated, `BAYS = 4` in firmware — document?

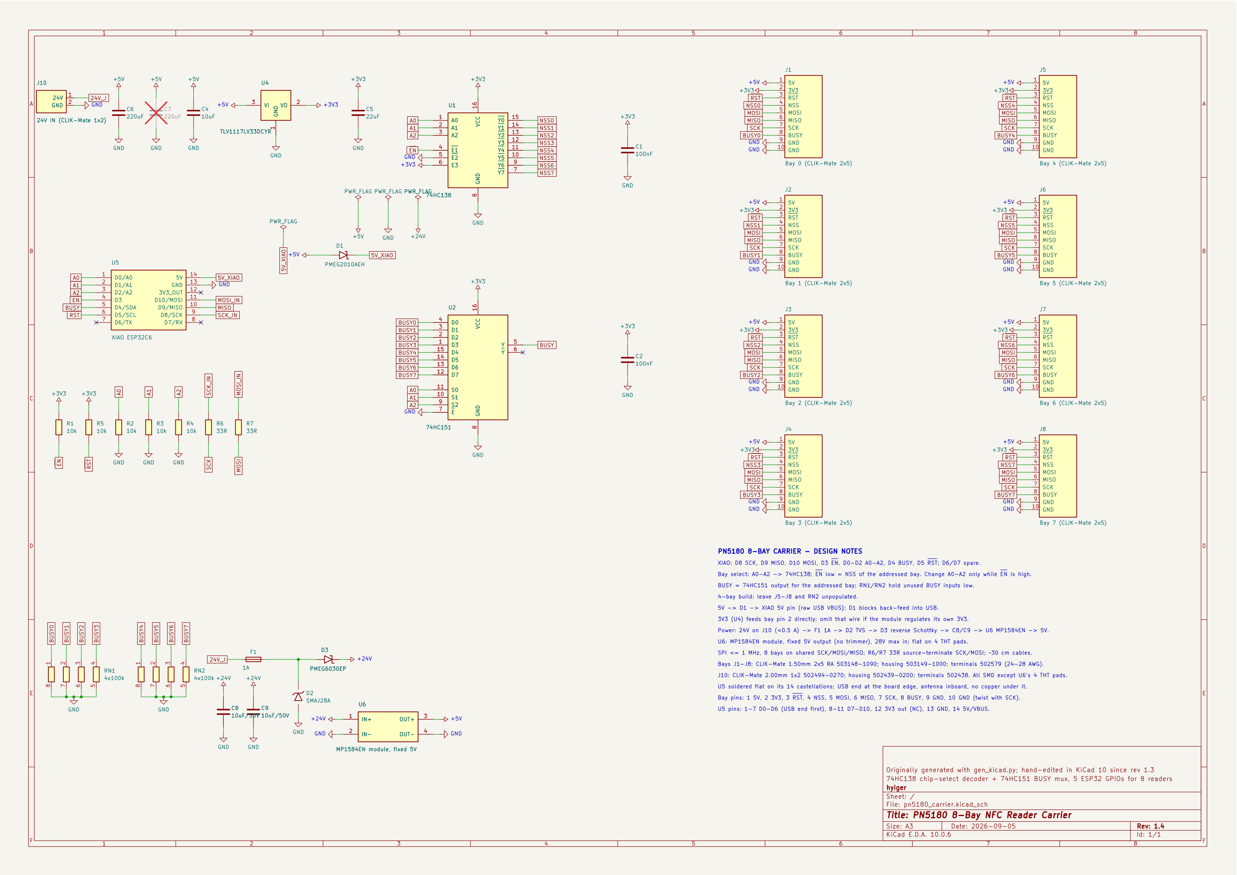
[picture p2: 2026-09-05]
pn5180_carrier_schematic.png

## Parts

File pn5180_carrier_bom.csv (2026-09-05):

References | Qty | Value | Type | Manufacturer | MPN | Mouser Part Number | Footprint | Populate | Description
C1, C2 | 2 | 100nF | C | Murata | GRM188R71H104KA93D | 81-GRM188R71H104KA93D | Capacitor_SMD:C_0603_1608Metric_Pad1.08x0.95mm_HandSolder |  | 100nF 50V X7R 0603
C4 | 1 | 10uF | C | Murata | GRM188R61A106KE69D | 81-GRM188R61A106KE69D | Capacitor_SMD:C_0603_1608Metric_Pad1.08x0.95mm_HandSolder |  | 10uF 10V X5R 0603
C5 | 1 | 22uF | C | Murata | GRM188R60J226MEA0D | 81-GRM188R60J226MEA0D | Capacitor_SMD:C_0603_1608Metric_Pad1.08x0.95mm_HandSolder |  | 22uF 6.3V X5R 0603
C6 | 1 | 220uF | C | Taiyo Yuden | MSASJ32MAB5227MPNDT1 | 963-MSASJ32MAB5227MP | Capacitor_SMD:C_1210_3225Metric_Pad1.33x2.70mm_HandSolder |  | 220uF 6.3V X5R 1210
C7 | 1 | 220uF | C | Taiyo Yuden | MSASJ32MAB5227MPNDT1 | 963-MSASJ32MAB5227MP | Capacitor_SMD:C_1210_3225Metric_Pad1.33x2.70mm_HandSolder | DNP | 220uF 6.3V X5R 1210
C8, C9 | 2 | 10uF/50V | C | Murata | GRM32ER71H106KA12L | 81-GRM32ER71H106KA12L | Capacitor_SMD:C_1210_3225Metric_Pad1.33x2.70mm_HandSolder |  | 10uF 50V X7R 1210
D1 | 1 | PMEG2010AEH | D | Nexperia | PMEG2010AEH | 771-PMEG2010AEH | Diode_SMD:D_SOD-123 |  | Schottky 20V 1A SOD-123
D2 | 1 | SMAJ28A | D | Littelfuse | SMAJ28A | 576-SMAJ28A | Diode_SMD:D_SMA |  | TVS 28V standoff, 400W, SMA
D3 | 1 | PMEG6030EP | D | Nexperia | PMEG6030EP | 771-PMEG6030EP | Diode_SMD:D_SOD-128 |  | Schottky 60V 3A SOD-128 (reverse polarity)
F1 | 1 | 1A NANO2 | F | Littelfuse | 0453001.MR | 576-0453001.MR | carrier:Fuse_Littelfuse-NANO2-451_453 |  | 1A SMD fuse, NANO2 451/453 (fast-acting series; Slo-Blo is 452/454 — see CLAUDE.md open item 13)
J1, J2, J3, J4, J5, J6, J7, J8 | 8 | CLIK-Mate 1.50mm dual-row RA SMT receptacle 2x5, positive lock | J | Molex | 503148-1090 | 538-503148-1090 | carrier:Molex_CLIK-Mate_503148-1090_2x05-1MP_P1.50mm_Horizontal |  | CLIK-Mate 1.50mm dual-row RA SMT receptacle 2x5, positive lock
J10 | 1 | 24V IN (CLIK-Mate 1x2) | J | Molex | 502494-0270 | 538-502494-0270 | carrier:Molex_CLIK-Mate_502494-0270_1x02-1MP_P2.00mm_Horizontal |  | CLIK-Mate 2.00mm RA SMT receptacle 1x2, positive lock
R1, R2, R3, R4, R5 | 5 | 10k | R | Yageo | RC0603FR-0710KL | 603-RC0603FR-0710KL | Resistor_SMD:R_0603_1608Metric_Pad0.98x0.95mm_HandSolder |  | 10k 1% 0603
R6, R7 | 2 | 33R | R | Yageo | RC0603FR-0733RL | 603-RC0603FR-0733RL | Resistor_SMD:R_0603_1608Metric_Pad0.98x0.95mm_HandSolder |  | 33R 1% 0603
RN1, RN2 | 2 | 4x100k | RN | Yageo | YC164-FR-07100KL | 603-YC164-FR-07100KL | Resistor_SMD:R_Array_Convex_4x0603 |  | 4x100k 1% isolated array, 0603x4
U1 | 1 | 74HC138 | U | Texas Instruments | SN74HC138DR | 595-SN74HC138DR | Package_SO:SOIC-16_3.9x9.9mm_P1.27mm |  | 3-to-8 decoder, SOIC-16
U2 | 1 | 74HC151 | U | Texas Instruments | SN74HC151DR | 595-SN74HC151DR | Package_SO:SOIC-16_3.9x9.9mm_P1.27mm |  | 8:1 mux, SOIC-16
U4 | 1 | TLV1117LV33DCYR | U | Texas Instruments | TLV1117LV33DCYR | 595-TLV1117LV33DCYR | Package_TO_SOT_SMD:SOT-223-3_TabPin2 |  | 3.3V 1A LDO, ceramic-stable, SOT-223
U5 | 1 | XIAO ESP32C6 | U | Seeed Studio | XIAO ESP32C6 | 713-113991182 | carrier:Seeed_XIAO_ESP32C6_SMD |  | XIAO ESP32C6 module (Seeed SKU 113991182), soldered flat on its 14 castellations (user-supplied; verify Mouser #)
U6 | 1 | MP1584EN module, fixed 5V | U | Generic (D-SUN style) | MP1584EN mini buck module (fixed 5V output) |  | carrier:MP1584EN_Module_22x17 |  | 22x17mm fixed-5V module (no trimmer), user-supplied (Amazon)

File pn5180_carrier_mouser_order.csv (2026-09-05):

Mouser Part Number | Quantity | Manufacturer Part Number | Description | Customer Part Number
81-GRM188R71H104KA93D | 2 | GRM188R71H104KA93D | 100nF 50V X7R 0603 | C1, C2
81-GRM188R61A106KE69D | 1 | GRM188R61A106KE69D | 10uF 10V X5R 0603 | C4
81-GRM188R60J226MEA0D | 1 | GRM188R60J226MEA0D | 22uF 6.3V X5R 0603 | C5
963-MSASJ32MAB5227MP | 1 | MSASJ32MAB5227MPNDT1 | 220uF 6.3V X5R 1210 | C6
81-GRM32ER71H106KA12L | 2 | GRM32ER71H106KA12L | 10uF 50V X7R 1210 | C8, C9
771-PMEG2010AEH | 1 | PMEG2010AEH | Schottky 20V 1A SOD-123 | D1
576-SMAJ28A | 1 | SMAJ28A | TVS 28V standoff, 400W, SMA | D2
771-PMEG6030EP | 1 | PMEG6030EP | Schottky 60V 3A SOD-128 (reverse polarity) | D3
576-0453001.MR | 1 | 0453001.MR | 1A SMD fuse, NANO2 451/453 (fast-acting series; Slo-Blo is 452/454 — see CLAUDE.md open item 13) | F1
538-503148-1090 | 8 | 503148-1090 | CLIK-Mate 1.50mm dual-row RA SMT receptacle 2x5, positive lock | J1, J2, J3, J4, J5, J6, J7, J8
538-502494-0270 | 1 | 502494-0270 | CLIK-Mate 2.00mm RA SMT receptacle 1x2, positive lock | J10
603-RC0603FR-0710KL | 5 | RC0603FR-0710KL | 10k 1% 0603 | R1, R2, R3, R4, R5
603-RC0603FR-0733RL | 2 | RC0603FR-0733RL | 33R 1% 0603 | R6, R7
603-YC164-FR-07100KL | 2 | YC164-FR-07100KL | 4x100k 1% isolated array, 0603x4 | RN1, RN2
595-SN74HC138DR | 1 | SN74HC138DR | 3-to-8 decoder, SOIC-16 | U1
595-SN74HC151DR | 1 | SN74HC151DR | 8:1 mux, SOIC-16 | U2
595-TLV1117LV33DCYR | 1 | TLV1117LV33DCYR | 3.3V 1A LDO, ceramic-stable, SOT-223 | U4
713-113991182 | 1 | XIAO ESP32C6 | XIAO ESP32C6 module (Seeed SKU 113991182), soldered flat on its 14 castellations (user-supplied; verify Mouser #) | U5
538-503149-1000 | 8 | 503149-1000 | CLIK-Mate 1.50mm dual-row positive-lock plug housing 2x5 (bay cables) | cable
538-502439-0200 | 1 | 502439-0200 | CLIK-Mate 2.00mm positive-lock housing 1x2 (24V cable) | cable
538-502579-0000-CT | 100 | 502579-0000 (Cut Strip) | CLIK-Mate 1.50mm crimp terminal, tin, 24-28 AWG, cut strip of 100 (80 needed + spares; thin-wall wire, insulation OD <= 1.28 mm) | cable
538-502438-0100 | 10 | 502438-0100 | CLIK-Mate 2.00mm crimp terminal, loose, tin, 22-26 AWG (2 needed for the 24 V cable + spares; confirm minimum at checkout) | cable

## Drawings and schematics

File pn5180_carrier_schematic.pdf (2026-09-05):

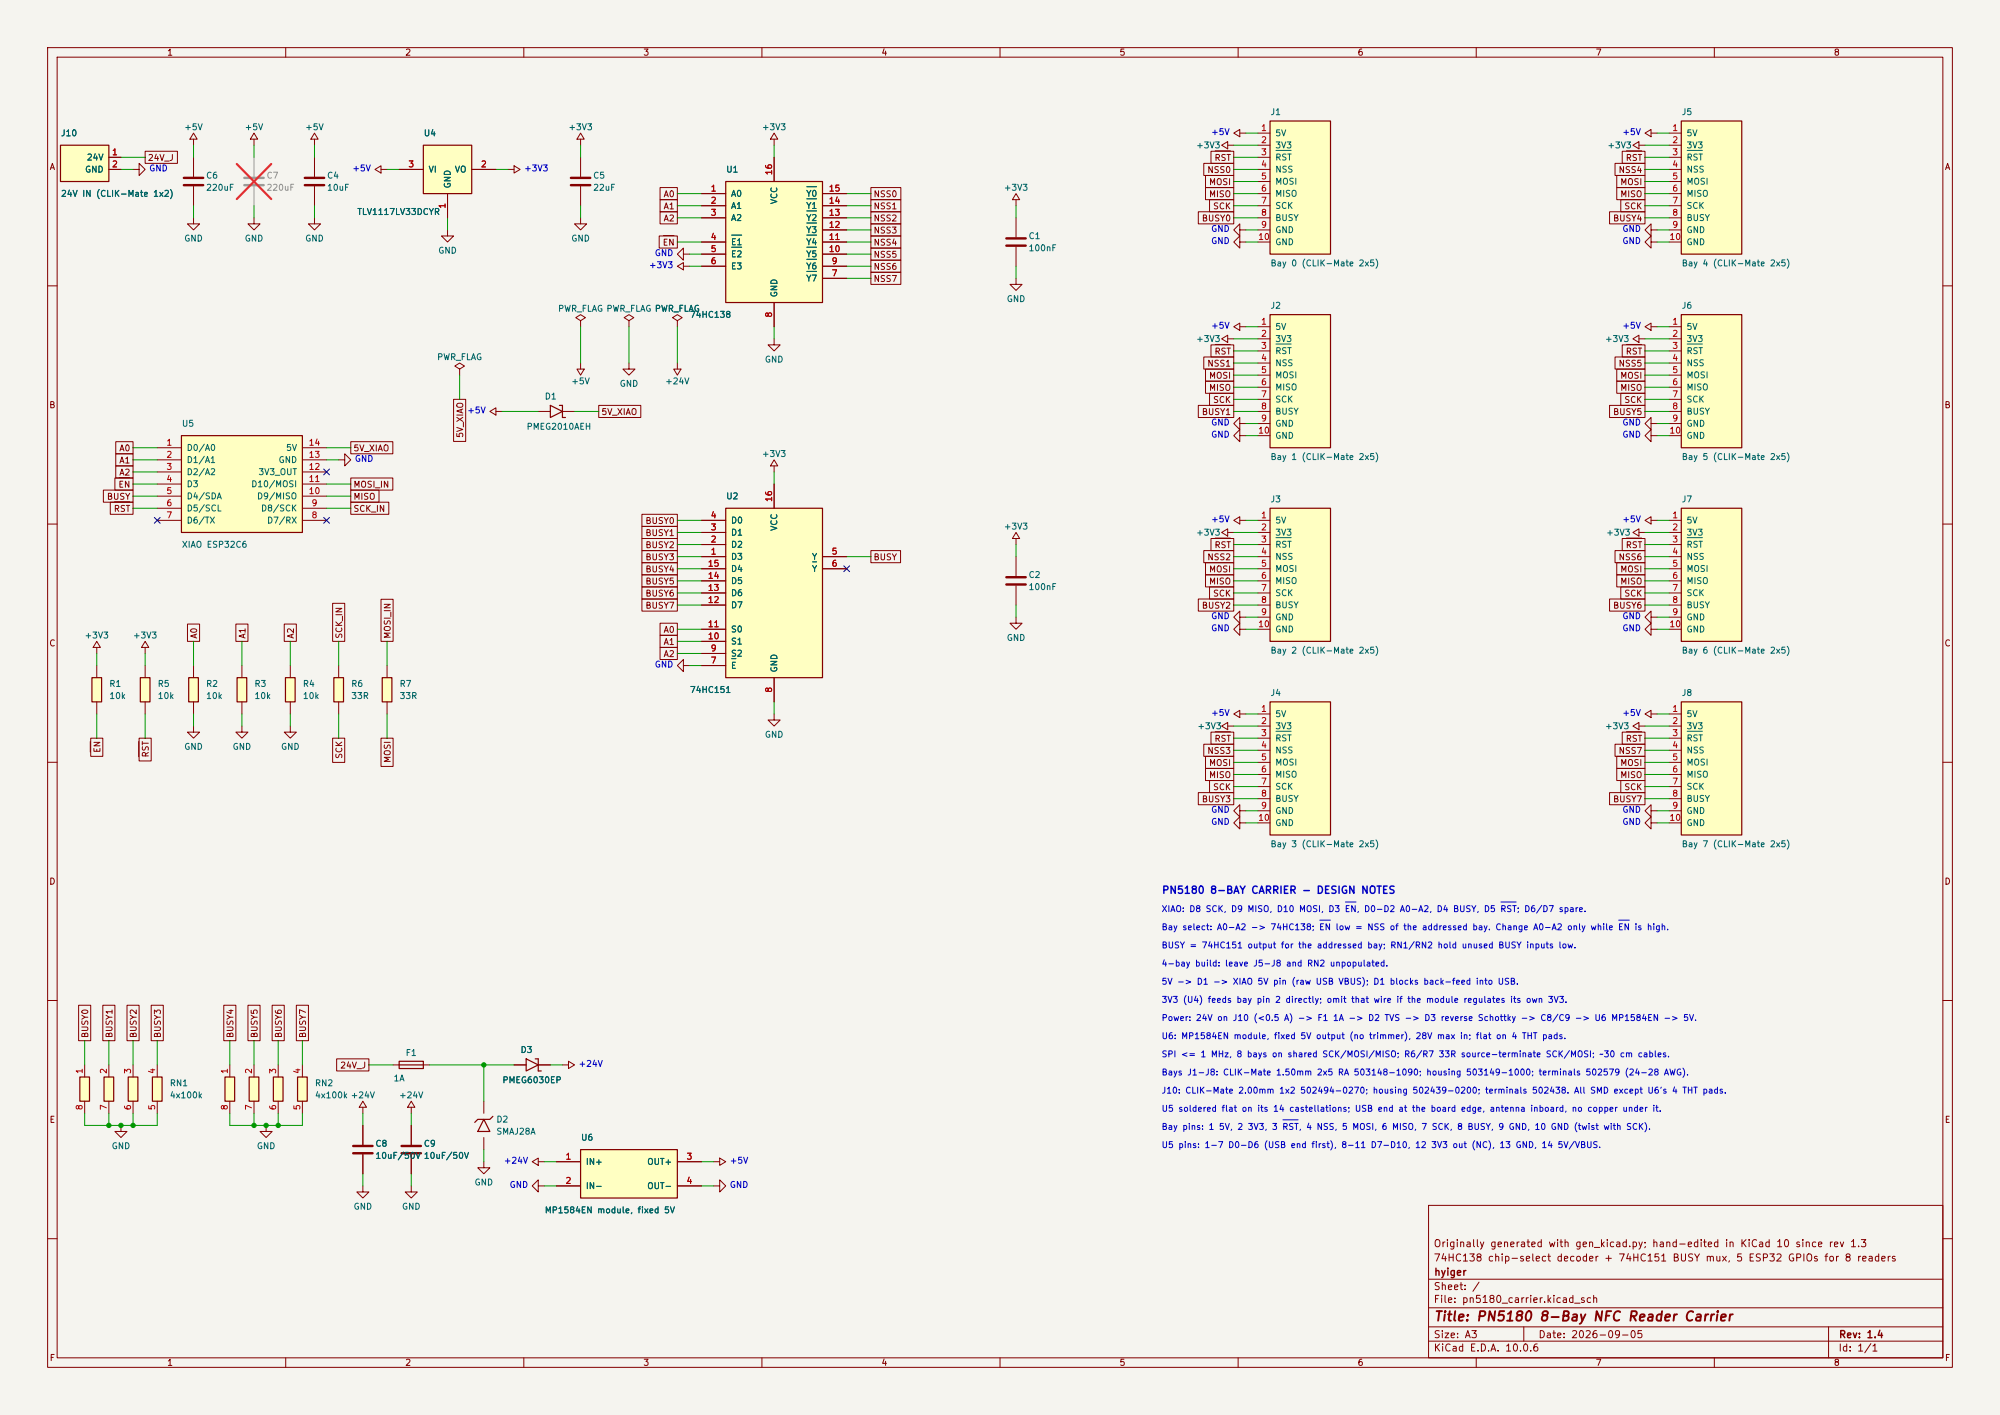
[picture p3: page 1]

+5V Bay select: A0-A2 -> 74HC138; EN low = NSS of the addressed bay. Change A0-A2 only while EN is high. U6: MP1584EN module, fixed 5V output (no trimmer), 28V max in; flat on 4 THT pads. GND

5V -> D1 -> XIAO 5V pin (raw USB VBUS); D1 blocks back-feed into USB. GND

XIAO: D8 SCK, D9 MISO, D10 MOSI, D3 EN, D0-D2 A0-A2, D4 BUSY, D5 RST; D6/D7 spare.

3V3 (U4) feeds bay pin 2 directly; omit that wire if the module regulates its own 3V3. BUSY = 74HC151 output for the addressed bay; RN1/RN2 hold unused BUSY inputs low.

Bays J1-J8: CLIK-Mate 1.50mm 2x5 RA 503148-1090; housing 503149-1000; terminals 502579 (24-28 AWG). Power: 24V on J10 (<0.5 A) -> F1 1A -> D2 TVS -> D3 reverse Schottky -> C8/C9 -> U6 MP1584EN -> 5V. U5 pins: 1-7 D0-D6 (USB end first), 8-11 D7-D10, 12 3V3 out (NC), 13 GND, 14 5V/VBUS.

Bay pins: 1 5V, 2 3V3, 3 RST, 4 NSS, 5 MOSI, 6 MISO, 7 SCK, 8 BUSY, 9 GND, 10 GND (twist with SCK). SPI <= 1 MHz, 8 bays on shared SCK/MOSI/MISO; R6/R7 33R source-terminate SCK/MOSI; ~30 cm cables. U5 soldered flat on its 14 castellations; USB end at the board edge, antenna inboard, no copper under it.

J10: CLIK-Mate 2.00mm 1x2 502494-0270; housing 502439-0200; terminals 502438. All SMD except U6's 4 THT pads.

Originally generated with gen_kicad.py; hand-edited in KiCad 10 since rev 1.3
74HC138 chip-select decoder + 74HC151 BUSY mux, 5 ESP32 GPIOs for 8 readers
hyiger
Sheet: /
File: pn5180_carrier.kicad_sch
Title: PN5180 8-Bay NFC Reader Carrier

Size: A3 | Rev: 1.4 | F Date: 2026-09-05
KiCad E.D.A. 10.0.6 | Id: 1/1

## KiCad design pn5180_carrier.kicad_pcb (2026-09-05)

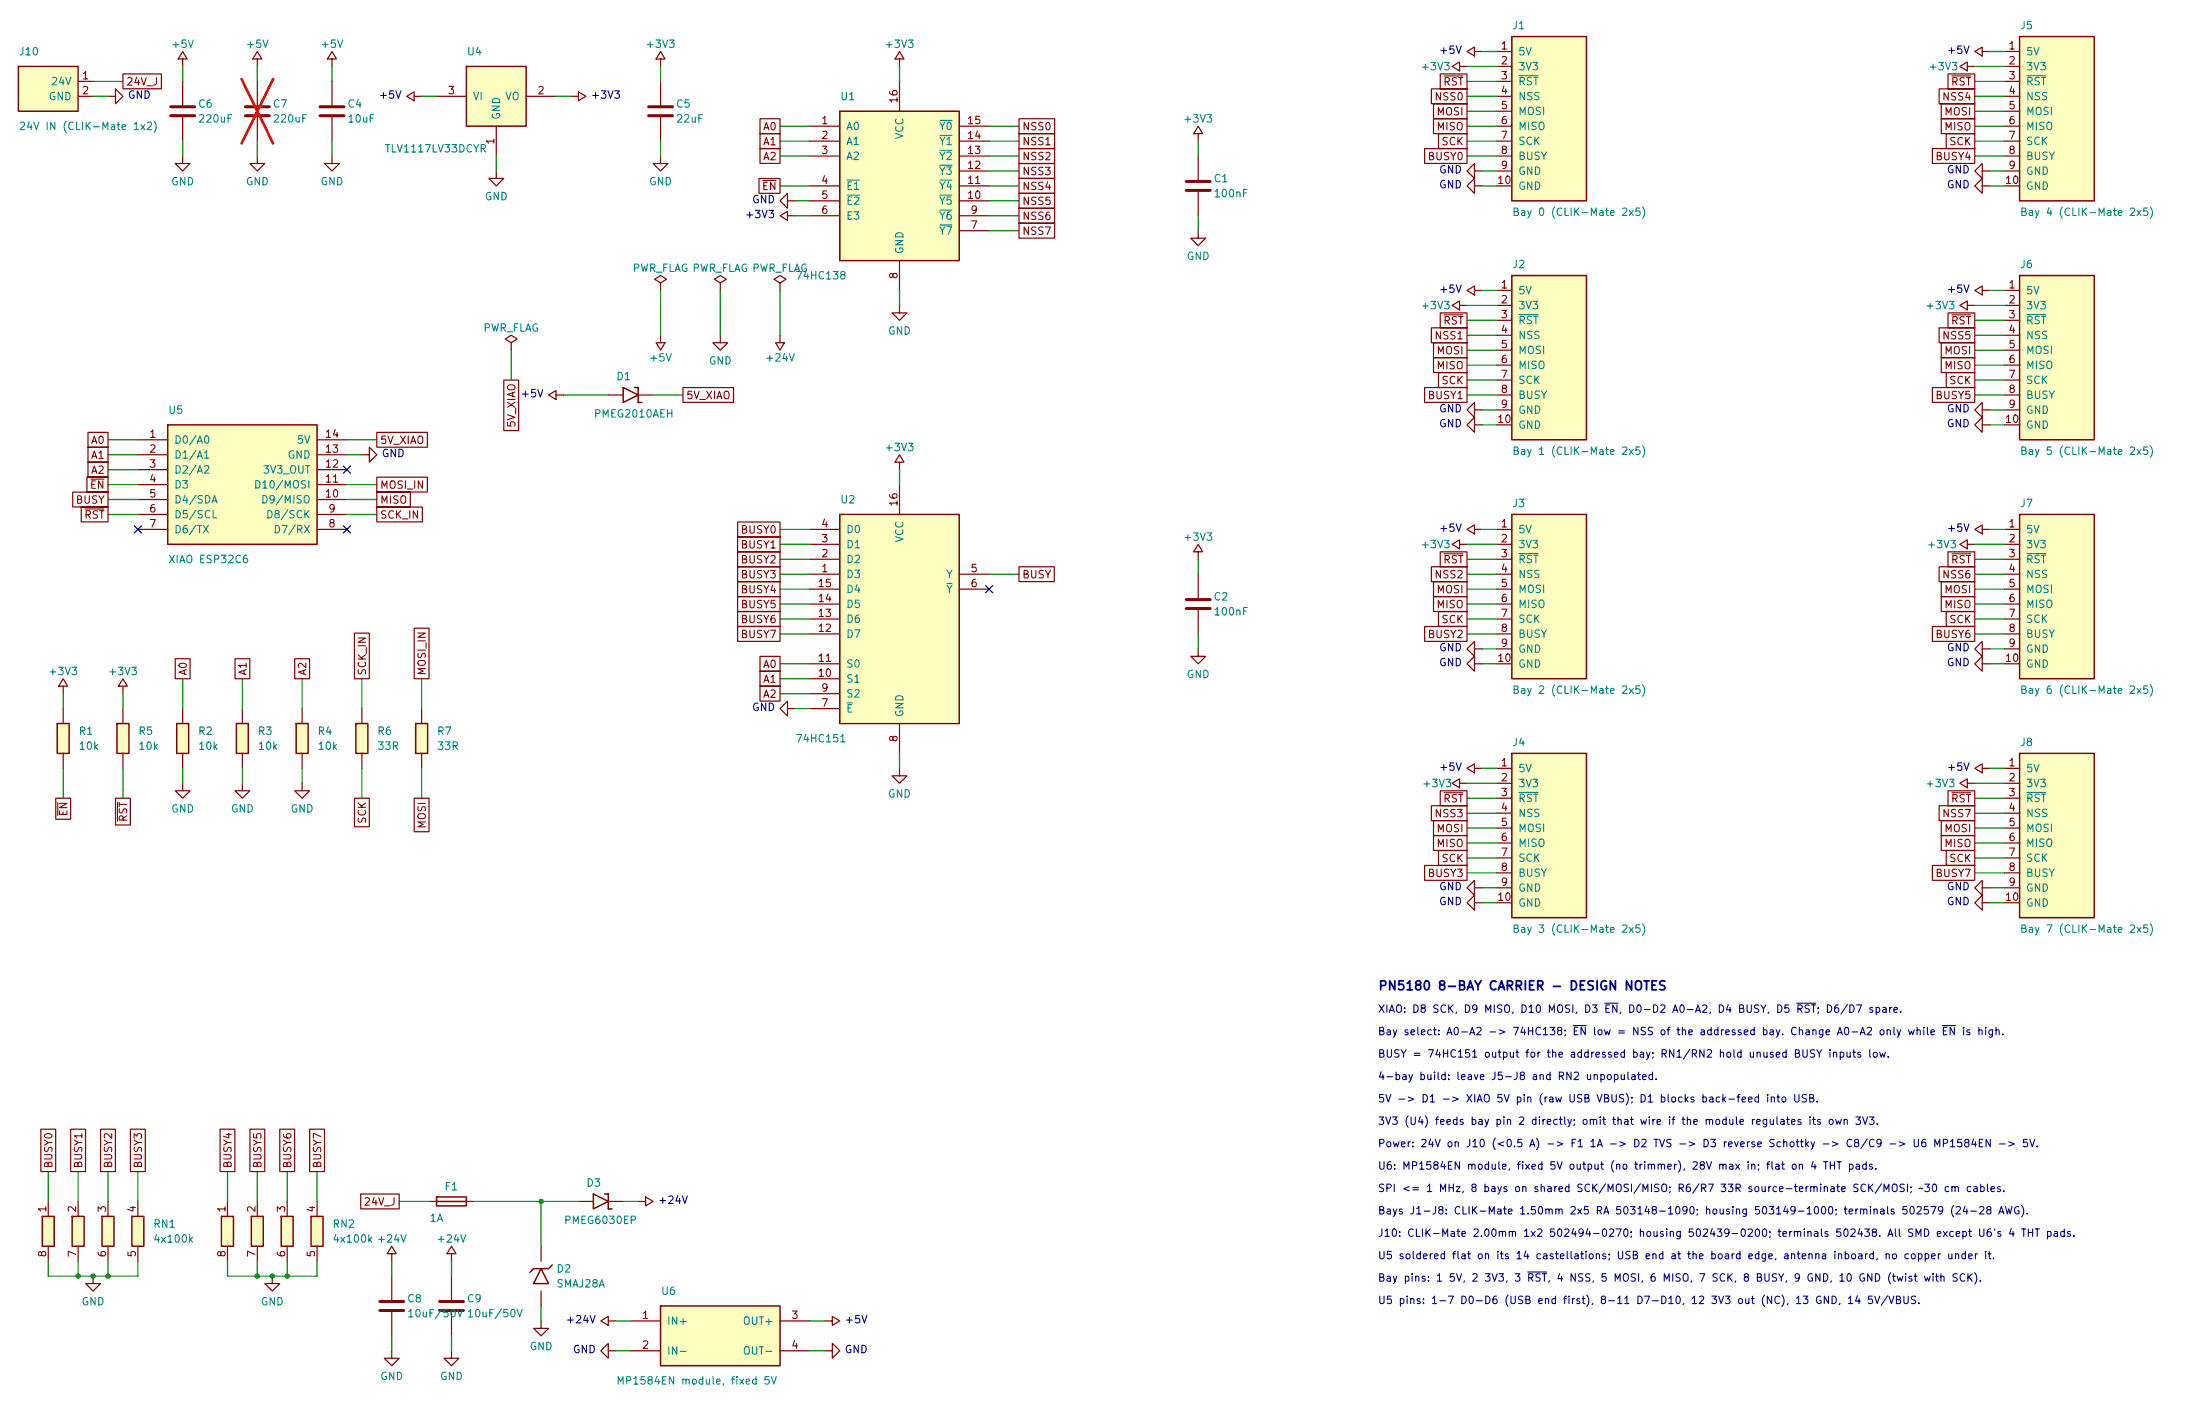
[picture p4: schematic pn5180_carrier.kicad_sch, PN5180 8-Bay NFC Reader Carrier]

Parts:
C1, C2: 100nF; C_0603_1608Metric_Pad1.08x0.95mm_HandSolder; MPN GRM188R71H104KA93D; Mouser 81-GRM188R71H104KA93D
C4: 10uF; C_0603_1608Metric_Pad1.08x0.95mm_HandSolder; MPN GRM188R61A106KE69D; Mouser 81-GRM188R61A106KE69D
C5: 22uF; C_0603_1608Metric_Pad1.08x0.95mm_HandSolder; MPN GRM188R60J226MEA0D; Mouser 81-GRM188R60J226MEA0D
C6: 220uF; C_1210_3225Metric_Pad1.33x2.70mm_HandSolder; MPN MSASJ32MAB5227MPNDT1; Mouser 963-MSASJ32MAB5227MP
C7: 220uF; C_1210_3225Metric_Pad1.33x2.70mm_HandSolder; MPN MSASJ32MAB5227MPNDT1; Mouser 963-MSASJ32MAB5227MP; not fitted
C8, C9: 10uF/50V; C_1210_3225Metric_Pad1.33x2.70mm_HandSolder; MPN GRM32ER71H106KA12L; Mouser 81-GRM32ER71H106KA12L
D1: PMEG2010AEH; D_SOD-123; MPN PMEG2010AEH; Mouser 771-PMEG2010AEH
D2: SMAJ28A; D_SMA; MPN SMAJ28A; Mouser 576-SMAJ28A
D3: PMEG6030EP; D_SOD-128; MPN PMEG6030EP; Mouser 771-PMEG6030EP
F1: 1A; Fuse_Littelfuse-NANO2-451_453; MPN 0453001.MR; Mouser 576-0453001.MR
J1: Bay 0 (CLIK-Mate 2x5); Molex_CLIK-Mate_503148-1090_2x05-1MP_P1.50mm_Horizontal; MPN 503148-1090; Mouser 538-503148-1090
J2: Bay 1 (CLIK-Mate 2x5); Molex_CLIK-Mate_503148-1090_2x05-1MP_P1.50mm_Horizontal; MPN 503148-1090; Mouser 538-503148-1090
J3: Bay 2 (CLIK-Mate 2x5); Molex_CLIK-Mate_503148-1090_2x05-1MP_P1.50mm_Horizontal; MPN 503148-1090; Mouser 538-503148-1090
J4: Bay 3 (CLIK-Mate 2x5); Molex_CLIK-Mate_503148-1090_2x05-1MP_P1.50mm_Horizontal; MPN 503148-1090; Mouser 538-503148-1090
J5: Bay 4 (CLIK-Mate 2x5); Molex_CLIK-Mate_503148-1090_2x05-1MP_P1.50mm_Horizontal; MPN 503148-1090; Mouser 538-503148-1090
J6: Bay 5 (CLIK-Mate 2x5); Molex_CLIK-Mate_503148-1090_2x05-1MP_P1.50mm_Horizontal; MPN 503148-1090; Mouser 538-503148-1090
J7: Bay 6 (CLIK-Mate 2x5); Molex_CLIK-Mate_503148-1090_2x05-1MP_P1.50mm_Horizontal; MPN 503148-1090; Mouser 538-503148-1090
J8: Bay 7 (CLIK-Mate 2x5); Molex_CLIK-Mate_503148-1090_2x05-1MP_P1.50mm_Horizontal; MPN 503148-1090; Mouser 538-503148-1090
J10: 24V IN (CLIK-Mate 1x2); Molex_CLIK-Mate_502494-0270_1x02-1MP_P2.00mm_Horizontal; MPN 502494-0270; Mouser 538-502494-0270
R1, R2, R3, R4, R5: 10k; R_0603_1608Metric_Pad0.98x0.95mm_HandSolder; MPN RC0603FR-0710KL; Mouser 603-RC0603FR-0710KL
R6, R7: 33R; R_0603_1608Metric_Pad0.98x0.95mm_HandSolder; MPN RC0603FR-0733RL; Mouser 603-RC0603FR-0733RL
RN1, RN2: 4x100k; R_Array_Convex_4x0603; MPN YC164-FR-07100KL; Mouser 603-YC164-FR-07100KL
U1: 74HC138; SOIC-16_3.9x9.9mm_P1.27mm; MPN SN74HC138DR; Mouser 595-SN74HC138DR
U2: 74HC151; SOIC-16_3.9x9.9mm_P1.27mm; MPN SN74HC151DR; Mouser 595-SN74HC151DR
U4: TLV1117LV33DCYR; SOT-223-3_TabPin2; MPN TLV1117LV33DCYR; Mouser 595-TLV1117LV33DCYR
U5: XIAO ESP32C6; Seeed_XIAO_ESP32C6_SMD; MPN XIAO ESP32C6; Mouser 713-113991182
U6: MP1584EN module, fixed 5V; MP1584EN_Module_22x17; MPN MP1584EN mini buck module

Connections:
5V_XIAO: D1.1 (K), U5.14 (5V)
24V_J: F1.1, J10.1 (24V)
+3V3: C1.1, C2.1, C5.1, J1.2 (3V3), J2.2 (3V3), J3.2 (3V3), J4.2 (3V3), J5.2 (3V3), J6.2 (3V3), J7.2 (3V3), J8.2 (3V3), R1.1, R5.1, U1.6 (E3), U1.16 (VCC), U2.16 (VCC), U4.2 (VO)
+5V: C4.1, C6.1, C7.1, D1.2 (A), J1.1 (5V), J2.1 (5V), J3.1 (5V), J4.1 (5V), J5.1 (5V), J6.1 (5V), J7.1 (5V), J8.1 (5V), U4.3 (VI), U6.3 (OUT+)
+24V: C8.1, C9.1, D3.1 (K), U6.1 (IN+)
A0: R2.1, U1.1 (A0), U2.11 (S0), U5.1 (D0/A0)
A1: R3.1, U1.2 (A1), U2.10 (S1), U5.2 (D1/A1)
A2: R4.1, U1.3 (A2), U2.9 (S2), U5.3 (D2/A2)
BUSY: U2.5 (Y), U5.5 (D4/SDA)
BUSY0: J1.8 (BUSY), RN1.1 (R1.1), U2.4 (D0)
BUSY1: J2.8 (BUSY), RN1.2 (R2.1), U2.3 (D1)
BUSY2: J3.8 (BUSY), RN1.3 (R3.1), U2.2 (D2)
BUSY3: J4.8 (BUSY), RN1.4 (R4.1), U2.1 (D3)
BUSY4: J5.8 (BUSY), RN2.1 (R1.1), U2.15 (D4)
BUSY5: J6.8 (BUSY), RN2.2 (R2.1), U2.14 (D5)
BUSY6: J7.8 (BUSY), RN2.3 (R3.1), U2.13 (D6)
BUSY7: J8.8 (BUSY), RN2.4 (R4.1), U2.12 (D7)
GND: C1.2, C2.2, C4.2, C5.2, C6.2, C7.2, C8.2, C9.2, D2.2 (A), J1.9 (GND), J1.10 (GND), J2.9 (GND), J2.10 (GND), J3.9 (GND), J3.10 (GND), J4.9 (GND), J4.10 (GND), J5.9 (GND), J5.10 (GND), J6.9 (GND), J6.10 (GND), J7.9 (GND), J7.10 (GND), J8.9 (GND), J8.10 (GND), J10.2 (GND), R2.2, R3.2, R4.2, RN1.5 (R4.2), RN1.6 (R3.2), RN1.7 (R2.2), RN1.8 (R1.2), RN2.5 (R4.2), RN2.6 (R3.2), RN2.7 (R2.2), RN2.8 (R1.2), U1.5 (~E2), U1.8 (GND), U2.7 (~E), U2.8 (GND), U4.1 (GND), U5.13 (GND), U6.2 (IN-), U6.4 (OUT-)
MISO: J1.6 (MISO), J2.6 (MISO), J3.6 (MISO), J4.6 (MISO), J5.6 (MISO), J6.6 (MISO), J7.6 (MISO), J8.6 (MISO), U5.10 (D9/MISO)
MOSI: J1.5 (MOSI), J2.5 (MOSI), J3.5 (MOSI), J4.5 (MOSI), J5.5 (MOSI), J6.5 (MOSI), J7.5 (MOSI), J8.5 (MOSI), R7.2
MOSI_IN: R7.1, U5.11 (D10/MOSI)
NSS0: J1.4 (NSS), U1.15 (~Y0)
NSS1: J2.4 (NSS), U1.14 (~Y1)
NSS2: J3.4 (NSS), U1.13 (~Y2)
NSS3: J4.4 (NSS), U1.12 (~Y3)
NSS4: J5.4 (NSS), U1.11 (~Y4)
NSS5: J6.4 (NSS), U1.10 (~Y5)
NSS6: J7.4 (NSS), U1.9 (~Y6)
NSS7: J8.4 (NSS), U1.7 (~Y7)
unnamed: D2.1 (K), D3.2 (A), F1.2
SCK: J1.7 (SCK), J2.7 (SCK), J3.7 (SCK), J4.7 (SCK), J5.7 (SCK), J6.7 (SCK), J7.7 (SCK), J8.7 (SCK), R6.2
SCK_IN: R6.1, U5.9 (D8/SCK)
~EN: R1.2, U1.4 (~E1), U5.4 (D3)
~RST: J1.3 (~RST), J2.3 (~RST), J3.3 (~RST), J4.3 (~RST), J5.3 (~RST), J6.3 (~RST), J7.3 (~RST), J8.3 (~RST), R5.2, U5.6 (D5/SCL)

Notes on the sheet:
U5 soldered flat on its 14 castellations; USB end at the board edge, antenna inboard, no copper under it.
GND
+5V
4-bay build: leave J5-J8 and RN2 unpopulated.
+24V
XIAO: D8 SCK, D9 MISO, D10 MOSI, D3 ~{EN}, D0-D2 A0-A2, D4 BUSY, D5 ~{RST}; D6/D7 spare.
SPI <= 1 MHz, 8 bays on shared SCK/MOSI/MISO; R6/R7 33R source-terminate SCK/MOSI; ~30 cm cables.
5V -> D1 -> XIAO 5V pin (raw USB VBUS); D1 blocks back-feed into USB.
U6: MP1584EN module, fixed 5V output (no trimmer), 28V max in; flat on 4 THT pads.
+3V3
Bay select: A0-A2 -> 74HC138; ~{EN} low = NSS of the addressed bay. Change A0-A2 only while ~{EN} is high.
PN5180 8-BAY CARRIER - DESIGN NOTES
Bay pins: 1 5V, 2 3V3, 3 ~{RST}, 4 NSS, 5 MOSI, 6 MISO, 7 SCK, 8 BUSY, 9 GND, 10 GND (twist with SCK).
BUSY = 74HC151 output for the addressed bay; RN1/RN2 hold unused BUSY inputs low.
U5 pins: 1-7 D0-D6 (USB end first), 8-11 D7-D10, 12 3V3 out (NC), 13 GND, 14 5V/VBUS.
Power: 24V on J10 (<0.5 A) -> F1 1A -> D2 TVS -> D3 reverse Schottky -> C8/C9 -> U6 MP1584EN -> 5V.
Bays J1-J8: CLIK-Mate 1.50mm 2x5 RA 503148-1090; housing 503149-1000; terminals 502579 (24-28 AWG).
3V3 (U4) feeds bay pin 2 directly; omit that wire if the module regulates its own 3V3.
J10: CLIK-Mate 2.00mm 1x2 502494-0270; housing 502439-0200; terminals 502438. All SMD except U6's 4 THT pads.

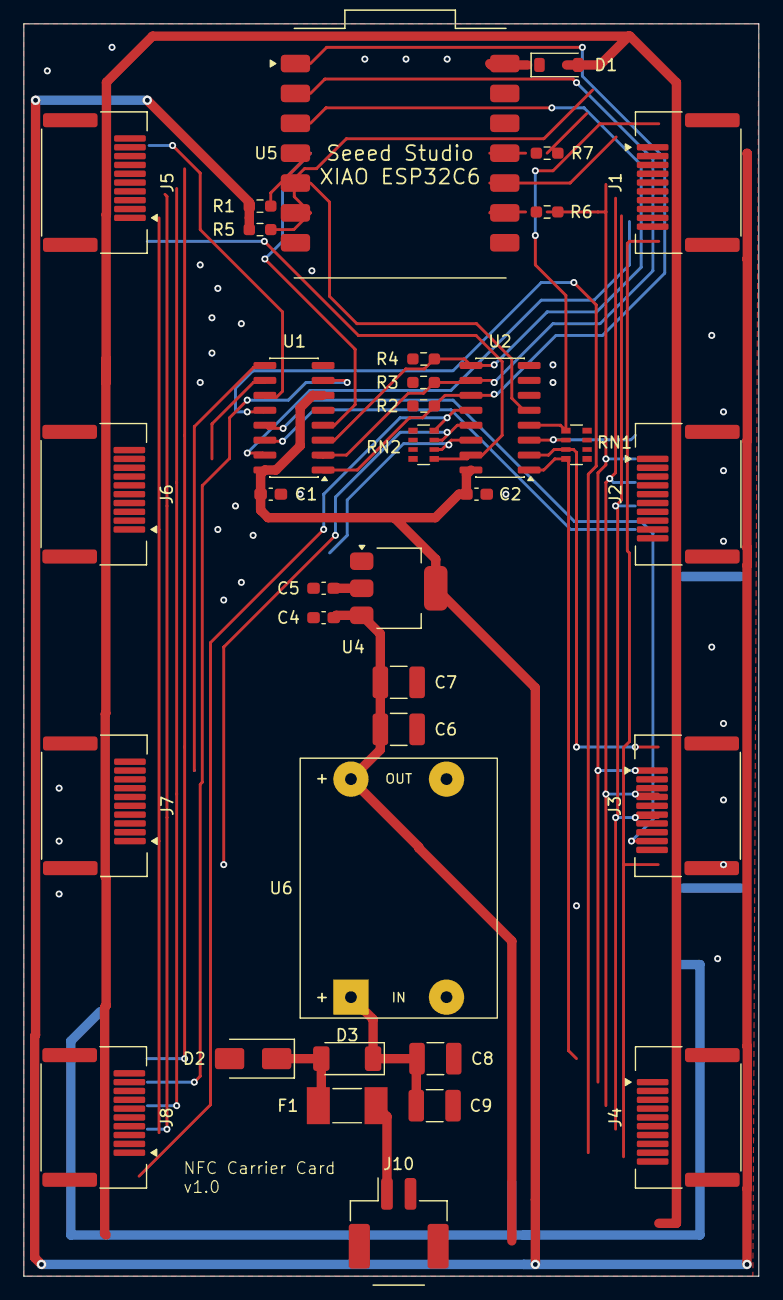
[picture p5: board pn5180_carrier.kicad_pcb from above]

Board: 2 copper layers, 62.5 x 106.5 mm, 35 parts (0 on the bottom side), 34 nets.

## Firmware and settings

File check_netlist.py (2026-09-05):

#!/usr/bin/env python3
"""Check a KiCad netlist export against the intended connectivity of the PN5180 carrier.

Usage:
    kicad-cli sch export netlist --format kicadsexpr -o net.txt pn5180_carrier.kicad_sch
    python3 check_netlist.py net.txt

EXPECTED below describes the design with JP1/JP2 removed (owner's current schematic):
  - D1 anode sits directly on +5V; D1 cathode -> 5V_XIAO -> XIAO pin 14
  - bay pin 2 sits directly on +3V3
If the owner's schematic names a net differently (e.g. kept a "3V3_BAY" label), the
script reports the difference — reconcile with the owner, then edit EXPECTED. Do not
"fix" the schematic to satisfy this file without asking.

Exit status 0 = all listed nets match exactly; 1 = differences found.
"""
import re, sys

J = lambda pin: {f"J{i}.{pin}" for i in range(1, 9)}

EXPECTED = {}
for i, n in enumerate((15, 14, 13, 12, 11, 10, 9, 7)):
    EXPECTED[f"NSS{i}"] = {f"J{i+1}.4", f"U1.{n}"}
for i, n in enumerate((4, 3, 2, 1, 15, 14, 13, 12)):
    EXPECTED[f"BUSY{i}"] = {f"J{i+1}.8", f"RN{1 + i // 4}.{i % 4 + 1}", f"U2.{n}"}
EXPECTED.update({
    "SCK":     J(7) | {"R6.2"},
    "SCK_IN":  {"R6.1", "U5.9"},
    "MOSI":    J(5) | {"R7.2"},
    "MOSI_IN": {"R7.1", "U5.11"},
    "MISO":    J(6) | {"U5.10"},
    "~{RST}":  J(3) | {"R5.2", "U5.6"},
    "A0":      {"R2.1", "U1.1", "U2.11", "U5.1"},
    "A1":      {"R3.1", "U1.2", "U2.10", "U5.2"},
    "A2":      {"R4.1", "U1.3", "U2.9",  "U5.3"},
    "~{EN}":   {"R1.2", "U1.4", "U5.4"},
    "BUSY":    {"U2.5", "U5.5"},
    "5V_XIAO": {"D1.1", "U5.14"},
    "24V_J":   {"J10.1", "F1.1"},
    # The fuse-to-TVS/Schottky node carries no label in the schematic (nor in gen_kicad.py);
    # KiCad auto-names it after D2's cathode. Add a "24V_F" global label if a fixed name is wanted.
    "Net-(D2-K)": {"F1.2", "D2.1", "D3.2"},
    "+24V":    {"D3.1", "C8.1", "C9.1", "U6.1"},
    "+5V":     J(1) | {"C4.1", "C6.1", "C7.1", "D1.2", "U4.3", "U6.3"},
    "+3V3":    J(2) | {"C1.1", "C2.1", "C5.1", "R1.1", "R5.1", "U1.16", "U1.6", "U2.16", "U4.2"},
    "GND":     J(9) | J(10) | {f"R{i}.2" for i in (2, 3, 4)}
               | {f"RN{n}.{p}" for n in (1, 2) for p in (5, 6, 7, 8)}
               | {"C1.2", "C2.2", "C4.2", "C5.2", "C6.2", "C7.2", "C8.2", "C9.2",
                  "D2.2", "J10.2", "U1.5", "U1.8", "U2.7", "U2.8", "U4.1", "U5.13",
                  "U6.2", "U6.4"},
})
# Pins that are intentionally unconnected (KiCad reports them as unconnected-(...) nets)
EXPECTED_NC = {"U2.6", "U5.7", "U5.8", "U5.12"}


def parse(path):
    txt = open(path).read()
    body = txt.split("(nets", 1)[1]
    nets = {}
    # Whitespace-tolerant: KiCad 7/8 wrote one node per line, KiCad 10 pretty-prints
    # one attribute per line.
    for block in re.split(r"\(net\b", body)[1:]:
        name = re.search(r'\(name\s+"([^"]*)"\)', block).group(1)
        nodes = re.findall(r'\(node\s+\(ref\s+"([^"]+)"\)\s+\(pin\s+"([^"]+)"\)', block)
        nets[name] = {f"{r}.{p}" for r, p in nodes}
    return nets


def main(path):
    nets = parse(path)
    bad = 0
    for name, want in EXPECTED.items():
        got = nets.get(name)
        if got is None:
            # maybe the same connectivity exists under another name
            alt = [n for n, v in nets.items() if v == want]
            print(f"MISSING net {name}" + (f" (same pins found as {alt[0]!r})" if alt else ""))
            bad += 1
            continue
        if got != want:
            print(f"MISMATCH {name}: extra={sorted(got - want)} missing={sorted(want - got)}")
            bad += 1
    nc = {p for n, v in nets.items() if n.startswith("unconnected-") for p in v}
    if nc != EXPECTED_NC:
        print(f"UNCONNECTED pins differ: extra={sorted(nc - EXPECTED_NC)} missing={sorted(EXPECTED_NC - nc)}")
        bad += 1
    known = set(EXPECTED) | {n for n in nets if n.startswith("unconnected-")}
    for n in sorted(set(nets) - known):
        print(f"UNEXPECTED net {n}: {sorted(nets[n])}")
        bad += 1
    print(f"{len(nets)} nets, {sum(len(v) for v in nets.values())} nodes, {bad} problem(s)")
    return 1 if bad else 0


if __name__ == "__main__":
    sys.exit(main(sys.argv[1] if len(sys.argv) > 1 else "net.txt"))

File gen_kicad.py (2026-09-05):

#!/usr/bin/env python3
"""Generate a KiCad 7-format project for the PN5180 8-bay carrier board.

All connectivity is done with short wire stubs + global labels / power symbols,
so every pin position is computed from the embedded symbol definitions.
"""
import uuid, json, os, datetime

G = 2.54
def g(n): return n * G
def U(): return str(uuid.uuid4())
def f(v):
    s = f"{v:.4f}".rstrip("0").rstrip(".")
    return "0" if s in ("", "-0") else s

PROJECT   = "pn5180_carrier"
OUTDIR    = os.path.dirname(os.path.abspath(__file__))  
ROOT_UUID = U()
LIBNAME   = "carrier"
FONT      = "(effects (font (size 1.27 1.27)))"
FONT_H    = "(effects (font (size 1.27 1.27)) hide)"

# ---------------------------------------------------------------------------
# Symbol library (lib coords: +y is UP, as in .kicad_sym files)
# pin tuple: (number, name, etype, x, y, rot, length)
#   rot 0 = pin on LEFT side pointing right, 180 = RIGHT side, 270 = TOP, 90 = BOTTOM
# ---------------------------------------------------------------------------
SYMS = {}

def add_sym(name, ref, body, pins, graphics="", pin_names_offset=1.016,
            hide_names=False, hide_numbers=False, power=False, desc=""):
    SYMS[name] = dict(ref=ref, body=body, pins={p[0]: p for p in pins},
                      pinlist=pins, graphics=graphics, off=pin_names_offset,
                      hide_names=hide_names, hide_numbers=hide_numbers,
                      power=power, desc=desc)

def lr(n, name, et, y, side, L=5.08):
    x = -(10.16 + L) if side == "L" else (10.16 + L)
    return (n, name, et, x, y, 0 if side == "L" else 180, L)

# 74HC138 3-to-8 decoder --------------------------------------------------
add_sym("74HC138", "U", (-10.16, 12.7, 10.16, -12.7), [
    lr("1", "A0", "input", 10.16, "L"), lr("2", "A1", "input", 7.62, "L"),
    lr("3", "A2", "input", 5.08, "L"),
    lr("4", "~{E1}", "input", 0, "L"), lr("5", "~{E2}", "input", -2.54, "L"),
    lr("6", "E3", "input", -5.08, "L"),
    lr("15", "~{Y0}", "output", 10.16, "R"), lr("14", "~{Y1}", "output", 7.62, "R"),
    lr("13", "~{Y2}", "output", 5.08, "R"), lr("12", "~{Y3}", "output", 2.54, "R"),
    lr("11", "~{Y4}", "output", 0, "R"), lr("10", "~{Y5}", "output", -2.54, "R"),
    lr("9", "~{Y6}", "output", -5.08, "R"), lr("7", "~{Y7}", "output", -7.62, "R"),
    ("16", "VCC", "power_in", 0, 17.78, 270, 5.08),
    ("8", "GND", "power_in", 0, -17.78, 90, 5.08),
], desc="3-to-8 line decoder, active-low outputs")

# 74HC151 8:1 multiplexer --------------------------------------------------
add_sym("74HC151", "U", (-10.16, 15.24, 10.16, -20.32), [
    lr("4", "D0", "input", 12.7, "L"), lr("3", "D1", "input", 10.16, "L"),
    lr("2", "D2", "input", 7.62, "L"), lr("1", "D3", "input", 5.08, "L"),
    lr("15", "D4", "input", 2.54, "L"), lr("14", "D5", "input", 0, "L"),
    lr("13", "D6", "input", -2.54, "L"), lr("12", "D7", "input", -5.08, "L"),
    lr("11", "S0", "input", -10.16, "L"), lr("10", "S1", "input", -12.7, "L"),
    lr("9", "S2", "input", -15.24, "L"), lr("7", "~{E}", "input", -17.78, "L"),
    lr("5", "Y", "output", 5.08, "R"), lr("6", "~{Y}", "output", 2.54, "R"),
    ("16", "VCC", "power_in", 0, 20.32, 270, 5.08),
    ("8", "GND", "power_in", 0, -25.4, 90, 5.08),
], desc="8-input multiplexer")

# TLV1117LV33 LDO ----------------------------------------------------------
add_sym("TLV1117LV33", "U", (-5.08, 5.08, 5.08, -5.08), [
    ("3", "VI", "power_in", -10.16, 0, 0, 5.08),
    ("2", "VO", "power_out", 10.16, 0, 180, 5.08),
    ("1", "GND", "power_in", 0, -10.16, 90, 5.08),
], desc="TI TLV1117LV33DCYR: 1A LDO, 3.3V fixed, ceramic-stable, Vin 2-5.5V, SOT-223 (1=GND 2=OUT/tab 3=IN)")

# Connectors ---------------------------------------------------------------
def conn(name, names, ref="J"):
    n = len(names)
    pins = [(str(i + 1), nm, "passive", -5.08, 12.7 - i * 2.54, 0, 2.54)
            for i, nm in enumerate(names)]
    body = (-2.54, 15.24, 10.16, 12.7 - (n - 1) * 2.54 - 2.54)
    add_sym(name, ref, body, pins, desc=f"{n}-pin connector")

conn("Conn_Bay", ["5V", "3V3", "~{RST}", "NSS", "MOSI", "MISO", "SCK", "BUSY", "GND", "GND"])
add_sym("Conn_PWR", "J", (-7.62, 5.08, 2.54, -2.54), [
    ("1", "24V", "passive", 5.08, 2.54, 180, 2.54),
    ("2", "GND", "passive", 5.08, 0, 180, 2.54),
], desc="2-way connector, 24V input from the printer PSU")

# Seeed XIAO ESP32C6 (socketed) --------------------------------------------
# Official Seeed numbering: 1-11 = D0-D10, 12 = 3V3 out, 13 = GND, 14 = 5V (USB VBUS)
XIAO_LEFT  = [("1", "D0/A0"), ("2", "D1/A1"), ("3", "D2/A2"), ("4", "D3"), ("5", "D4/SDA"),
              ("6", "D5/SCL"), ("7", "D6/TX")]
XIAO_RIGHT = [("14", "5V"), ("13", "GND"), ("12", "3V3_OUT"), ("11", "D10/MOSI"),
              ("10", "D9/MISO"), ("9", "D8/SCK"), ("8", "D7/RX")]
def _xt(nm):
    if nm == "GND" or nm == "5V": return "power_in"
    if nm == "3V3_OUT": return "power_out"
    return "bidirectional"
XIAO_PINS = [(n, nm, _xt(nm), -17.78, 7.62 - i * 2.54, 0, 5.08) for i, (n, nm) in enumerate(XIAO_LEFT)] + \
            [(n, nm, _xt(nm), 17.78, 7.62 - i * 2.54, 180, 5.08) for i, (n, nm) in enumerate(XIAO_RIGHT)]
add_sym("XIAO-ESP32C6", "U", (-12.7, 10.16, 12.7, -10.16), XIAO_PINS,
        desc="Seeed Studio XIAO ESP32C6 on two 1x7 sockets; pin numbers per Seeed's library (USB end = pins 1 and 14)")

# Schottky diode, KiCad convention pin 1 = K, pin 2 = A; drawn with A on the left
add_sym("D_Schottky", "D", None, [
    ("2", "A", "passive", -3.81, 0, 0, 2.54),
    ("1", "K", "passive", 3.81, 0, 180, 2.54),
], graphics="""
      (polyline (pts (xy -1.27 1.27) (xy -1.27 -1.27) (xy 1.27 0) (xy -1.27 1.27)) (stroke (width 0.254) (type default)) (fill (type none)))
      (polyline (pts (xy 1.27 1.27) (xy 1.27 -1.27)) (stroke (width 0.254) (type default)) (fill (type none)))
      (polyline (pts (xy 0.635 1.27) (xy 1.27 1.27)) (stroke (width 0.254) (type default)) (fill (type none)))
      (polyline (pts (xy 1.27 -1.27) (xy 1.905 -1.27)) (stroke (width 0.254) (type default)) (fill (type none)))""",
    hide_names=True, hide_numbers=True, pin_names_offset=0, desc="Schottky diode (SOD-123, pad 1 = cathode)")

# 24V -> 5V buck: MP1584EN mini module (22.1 x 16.8 mm, 4 pads) ---------------
add_sym("MP1584EN_Module", "U", (-10.16, 5.08, 10.16, -5.08), [
    ("1", "IN+", "power_in", -15.24, 2.54, 0, 5.08),
    ("2", "IN-", "power_in", -15.24, -2.54, 0, 5.08),
    ("3", "OUT+", "power_out", 15.24, 2.54, 180, 5.08),
    ("4", "OUT-", "power_in", 15.24, -2.54, 180, 5.08),
], desc="MP1584EN mini buck module (D-SUN style, 22.1 x 16.8 mm), 4.5-28V in, set to 5.0V, 3A peak / 1.5A cont.")
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

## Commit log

2026-09-05 Initial import: PN5180 8-bay NFC reader carrier (KiCad 10)
    Schematic, PCB, project-local symbol/footprint libraries, BOM CSVs, netlist
    checker, generator script, gerber preview export, and the CLAUDE.md /
    MEMORY.md design guide and decision log.
    [pn5180_carrier-B_Cu.gbr, pn5180_carrier-B_Mask.gbr, pn5180_carrier-B_Paste.gbr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]
2026-09-05 PCB: zones refilled after the outline fix (KiCad 10 GUI save)
    [pn5180_carrier.kicad_pcb]
2026-09-05 Schematic notes: drop JP1/JP2 wording; re-export the PDF/PNG renders
    Two DESIGN NOTES text objects only; netlist (38 nets, 189 nodes, 0 problems)
    and ERC (1 error, 81 warnings) unchanged.
    [pn5180_carrier.kicad_sch]
2026-09-05 README: KiCad 10, PCB status, remove JP1/JP2
    - KiCad 10 file format and 10.0 library set; kicad-cli check commands
    - Files table covers the PCB, gerbers, checker, guide docs; the generator is
    historical
    - JP1/JP2 gone: bay pin 2 fed directly from U4, XIAO 5V through D1; Jumpers
    section and BOM rows removed; same row dropped from pn5180_carrier_bom.csv
    - Layout notes reflect the actual placement (U5 top centre, bays on both edges)
    - Fix stale BUSY pin reference (XIAO D4, symbol pin 5) and a dangling sentence
    - Mouser CSV: the 1x2 housing is the 24 V cable
    - CLAUDE.md/MEMORY.md: close the corresponding open items
    [pn5180_carrier_bom.csv, pn5180_carrier_mouser_order.csv]
2026-09-05 Schematic title block: BUSY mux (IRQ was removed in rev 1.3); re-export renders
    [pn5180_carrier.kicad_sch]
2026-09-05 README corrections from the verification pass
    - RN1/RN2 element-to-bay mapping was off by one
    - D3 sentence claimed a miswire spares the fuse; it does not (F1 blows via D2)
    - 16-bay note used ESP32 (Xtensa) HSPI/VSPI wording; the C6 has one SPI host
    - XIAO placement: USB end at the edge, antenna inboard (matches the PCB)
    - worst-case input current bounded by the module's 1.5 A rating
    - generator description, order-CSV description, .gitignore row
    - Mouser CSV: XIAO sockets tagged 'U5 sockets' instead of 'cable'
    [pn5180_carrier_mouser_order.csv]
2026-09-05 Bay connectors J1-J8: CLIK-Mate 1.50 mm dual-row 2x5 (503148-1090), rev 1.4
    - New project footprint carrier:Molex_CLIK-Mate_503148-1090_2x05-1MP_P1.50mm_Horizontal
    from Molex's catalog drawing (10 pads 0.55x2.70 at 0.75 mm in one line at the rear,
    nail pads 1.20x4.65 at the front corners, body 11.8x8.75). Nail-pad fore-aft position
    and the sequential pad order are to be confirmed on SD-503148-1090.
    - Schematic: J1-J8 footprint/MPN/Mouser/description/value fields, DESIGN NOTES text,
    title-block rev 1.3 -> 1.4. Netlist (38 nets, 189 nodes, 0 problems) and ERC unchanged.
    - BOM CSV and Mouser order list: 503148-1090 x8, housing 503149-1000 x8, terminals
    502579-0000 cut strip of 100; th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
    [pn5180_carrier.kicad_sch, pn5180_carrier_bom.csv, pn5180_carrier_mouser_order.csv]
2026-09-05 2x5 connector: footprint corrections from the verification pass, doc fixes
    - Footprint: pad line offset 0.375 mm toward pin 10 (pads +3.0 .. -3.75), nail pads
    moved to the mating-face datum (centre Y +2.05), courtyard front to +5.0, silk stub
    and pin-1 triangle adjusted, descr rewritten. Scratch DRC with the project rules: 0.
    - Schematic: U5 note (USB end at the edge, antenna inboard), title-block date 2026-09-05,
    comment 2 reworded; renders re-exported. Netlist and ERC unchanged.
    - README: PCB/gerbers still carry the 1x10 parts; cable build by circuit number with the
    pairing marked as inferred; terminal insulation range 0.78-1.28 mm; crimper guidance;
    old 1x10 length 24.0 mm; dist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
    [pn5180_carrier.kicad_sch]
2026-09-05 Schematic DESIGN NOTES: terse one-line notes that fit the A3 frame; re-export renders
    Netlist (38 nets, 189 nodes, 0 problems) and ERC unchanged.
    [pn5180_carrier.kicad_sch]
2026-09-05 MEMORY: J10 stays on the 2.00 mm CLIK-Mate (decided 2026-09-05)
2026-09-05 PCB: J1-J8 swapped to the 2x5 CLIK-Mate footprint (Update PCB from Schematic, KiCad GUI)
    Same positions and orientations as the 1x10 parts; tracks to the bay connectors
    still need re-routing. Project file records schematic rev 1.4.
    [pn5180_carrier.kicad_pcb]
2026-09-05 3D models for the parts KiCad ships none for; preview render and tools
    - carrier.3dshapes/: simplified VRML models generated by tools/gen_3d_models.py —
    CLIK-Mate 503148-1090 2x5 and 502494-0270 1x2 receptacles, XIAO ESP32C6 on its two
    8.5 mm sockets (rounded board, castellations, USB-C, shield, u.FL, chip antenna,
    buttons), MP1584EN module, Littelfuse NANO2 fuse
    - carrier.pretty: model references on the three custom footprints; project-local
    copies of the stock J10 and F1 footprints that differ only in the model path;
    schematic/BOM/README point J10 and F1 at carrier:
    - PCB: model references text-patched into the embedded footprints (all 35 resolve);
    otherwise identical to the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
    [pn5180_carrier.kicad_pcb, pn5180_carrier.kicad_sch, pn5180_carrier_bom.csv]
2026-09-05 XIAO soldered flat (castellated SMD footprint), photo-accurate XIAO and MP1584EN models
    - carrier.pretty/Seeed_XIAO_ESP32C6_SMD (tools/gen_xiao_smd_fp.py): 14 pads 1.5x2.5 at
    2.54 mm on the module edges, same 1-14 numbering; U5 switched in the schematic, BOM
    and (by script, same position/nets/fields) on the PCB; the Wuerth sockets leave the
    Mouser order list. Tracks to U5 end 1.27 mm short of the new pads (re-route).
    - 3D: XIAO rebuilt from the owner's photos (rounded board, half-hole castellations,
    USB-C over the edge, R/B buttons and LEDs, white shield, u.FL, chip antenna), flat and
    socketed variants; MP1584EN per the owner's photo (black PCB, shielded inductor,
    SOIC-8, ceramic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
    [pn5180_carrier.kicad_pcb, pn5180_carrier.kicad_sch, pn5180_carrier_bom.csv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]
2026-09-05 Docs and model fixes from the flat-XIAO verification pass
    - README/CLAUDE.md/MEMORY.md: remaining "socketed" wording, F1 called fast-acting
    everywhere the docs speak, nail-pad-to-edge as a 1.575-1.675 mm range, XIAO placement
    numbers for the SMD footprint, post-swap DRC attribution (U5 /EN open via the B.Cu jog,
    3 shorts at pad 5), open items 1/2/3/9/13/14 updated; item 14 now lists the pending
    GUI work (re-route U5, F.Cu keep-out under the module's underside pads, hide the
    MPN/Mouser silk fields, fix the U5/F1 schematic field texts)
    - Mouser CSV: F1 and U5 descriptions aligned with the BOM CSV
    - Models: 0603 on the MP1584EN module moved off the corner ring, SOIC pins centred;
    re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
    [pn5180_carrier_mouser_order.csv]
2026-09-05 PCB: owner's routing session saved at 12:15 (KiCad GUI)
    [pn5180_carrier.kicad_pcb]
2026-09-05 U6 is the fixed-5 V module: strip the pot-setting text; align U5/F1 fields
    - U6: Value "MP1584EN module, fixed 5V", Description and library ki_description say
    fixed 5V output (no trimmer); DESIGN NOTES line, BOM CSV, README §buck and BOM row
    reworded; CLAUDE.md open item 9 resolved, MEMORY.md item 7 and open question closed.
    - U5: MPN "XIAO ESP32C6" in the schematic to match the owner's shortened PCB silk
    field (SKU 113991182 moved into Description) — DRC parity back to 0; Description
    and the two DESIGN NOTES lines now say soldered flat on 14 castellations, no sockets.
    - F1: Value "1A", Description "NANO2 451/453 (fast-acting series)" in schematic and PCB.
    - Re-exported schematic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
    [pn5180_carrier.kicad_pcb, pn5180_carrier.kicad_sch, pn5180_carrier_bom.csv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]
